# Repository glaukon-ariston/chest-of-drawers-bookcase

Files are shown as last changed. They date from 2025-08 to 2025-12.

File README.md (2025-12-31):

# Vibe Coding Furniture: Chest of Drawers Bookcase

This project contains the OpenSCAD code for a chest of drawers with an integrated bookcase.

## Prerequisites

- [Git](https://git-scm.com/downloads/win)
- [Node.js](https://nodejs.org/en/download/)
- [ezdxf](https://pypi.org/project/ezdxf/)
- [openpyxl](https://pypi.org/project/openpyxl/)
- [ODA File Converter](https://www.opendesign.com/guestfiles/oda_file_Converter)
- [LibreCAD](https://github.com/LibreCAD/LibreCAD/releases)
- [OpenSCAD](https://openscad.org/downloads.html#windows)
- [OpenSCAD (Nightly Build)](https://openscad.org/downloads.html#snapshots)
- [Gemini CLI](https://github.com/google-gemini/gemini-cli)
- [Visual Studio Code](https://code.visualstudio.com/)
- VS Code Extensions
    - Gemini Code Assist
    - Gemini CLI Companion
    - OpenSCAD

## Files

*   `model.scad`: The main OpenSCAD file containing the 3D model of the furniture.
*   `prompt/model.md`: The detailed instructions and dimensions used to generate the `model.scad` file.
*   `prompt/model-v2.md`: The updated instructions and dimensions for the v2 model.
*   `ps-modules/CommonFunctions.psm1`: A PowerShell module containing common functions used by the other scripts.
*   `artifacts/conversation.md`: A log of the conversation with Gemini CLI.
*   `workflow.ps1`: Orchestrates the entire workflow for generating various outputs from the OpenSCAD model.
*   `generate-csv.ps1`: Generates a CSV file with panel information.
*   `export-all.ps1`: Automates the export of all panels to various formats.
*   `export-panels.ps1`: Exports panels to a specific format (STL, DXF, SVG).
*   `run-split-layers.ps1`: Executes the `split-layers-dxf.ps1` script and logs the output.
*   `split_layers.py`: Python script to split DXF layers, add a title, annotations, a legend, a hole schedule and dimensions.
*   `convert-dxf-to-dwg.ps1`: Converts DXF files to DWG format using the ODA File Converter.
*   `convert-dxf-to-pdf.ps1`: Converts DXF files to PDF format using LibreCAD.
*   `create_order.py`: A Python script to generate an order document for the Iverpan cutting service.

## Model Description

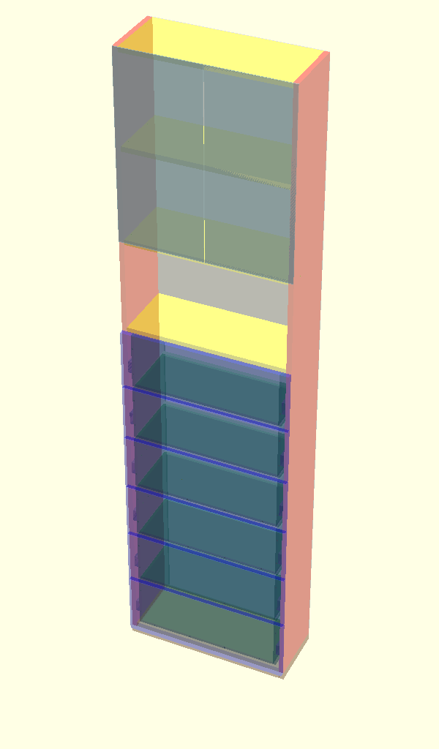
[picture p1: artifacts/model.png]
Model


The 3D model is a chest of drawers with an integrated bookcase. The design is parametric and all dimensions are derived from the main dimensions.

### Main Dimensions

*   **Corpus:**
    *   corpus_height = 2300
    *   corpus_width = 600
    *   corpus_depth = 230
*   **Melanine material thickness:**
    *   melanine_thickness_main = 18
    *   melanine_thickness_secondary = 10
*   **HDF Back Panel:**
    *   hdf_thickness = 3
*   **Pedestal:**
    *   pedestal_height = 30
*   **Shelves:**
    *   shelf_width = corpus_width - 2*melanine_thickness_main
    *   shelf_depth = corpus_depth
*   **Slides:**
    *   slide_width = 200
    *   slide_height = 45
    *   slide_depth = 13
*   **Drawers:**
    *   number_of_drawers = 6
    *   drawer_height = 200
    *   drawer_body_height = drawer_height - melanine_thickness_secondary
    *   drawer_depth = corpus_depth - 5
    *   drawer_width = shelf_width - 2*slide_depth
    *   drawer_body_width = drawer_width - 2*melanine_thickness_secondary
    *   drawer_bottom_offset = 10
    *   drawer_gap = 10
*   **Drawer Fronts:**
    *   front_gap = 3
    *   front_overhang = 3
    *   front_margin = 1.5
    *   front_width = corpus_width - 2 * front_margin
    *   front_height_base = drawer_height + drawer_gap - front_gap
    *   front_height_first = melanine_thickness_main + drawer_bottom_offset - front_gap + front_height_base
    *   front_height_standard = front_height_base
    *   front_height_top = front_height_standard + 3*front_overhang
*   **Bookcase Glass Doors:**
    *   bookcase_glass_door_width = (corpus_width - (1 + front_gap + 1))/2
    *   bookcase_glass_door_height = melanine_thickness_main + bookcase_shelf_gap + melanine_thickness_main + bookcase_shelf_gap + melanine_thickness_main/2
    *   bookcase_glass_door_tickness = 4
*   **Joinery:**
    *   confirmat_screw_length = 49
    *   confirmat_hole_diameter = 4
    *   confirmat_hole_edge_distance = 50
    *   dowel_diameter = 6
    *   dowel_length = 30
    *   dowel_hole_depth_in_front = 10
    *   dowel_hole_edge_distance = 50
    *   panel_length_for_four_dowels = 500
    *   slide_pilot_hole_depth = 2
    *   slide_pilot_hole_diameter = 2.5
    *   drawer_slide_pilot_hole_offsets = [37, 163]
    *   corpus_slide_pilot_hole_offsets = [6.5, 35, 51, 76, 99, 115]

### Structure

*   **Corpus:** The corpus is made of `melanine_thickness_main` thick melanine and consists of two sides, a top, a bottom and a middle plate. The corpus is divided into two compartments. The bottom compartment contains six drawers and the top compartment is a bookcase with two shelves.
*   **Drawers:** The drawers are made of `melanine_thickness_secondary` thick melanine and are mounted to the sides of the corpus with slides. Each drawer has a front panel made of `melanine_thickness_main` thick melanine. Dowel holes are included in the side and bottom panels for joining with the front panels. The drawer assembly has been fixed, and handle holes have been added to the drawer fronts.
*   **Shelves:** The bookcase has two shelves made of `melanine_thickness_main` thick melanine.
*   **HDF Back Panel:** A 3mm HDF back panel is attached to the back of the corpus.
*   **Pedestal:** A 30mm high pedestal is placed under the corpus.
*   **Glass Doors:** The bookcase section is enclosed by two glass doors.
*   **Joinery:** Confirmat screws (4.8mm x 49mm) are used to join the corpus panels and shelves. 4mm pilot holes for these screws are included in the model. The drawer components are also joined with these screws, with the number of screws depending on the panel length (2 for <50cm, 3 for >=50cm) and placed 5cm from the edge. Wooden dowels (phi 6 mm x 30 mm) are used to join the front panels to the drawer boxes. The front's blind hole is 1cm deep. There are two dowels per panel per side if the panel length is less than 50cm, and four dowels if longer, with even spacing. The hole locations are 5cm from the edge. Pilot holes for mounting the drawer slides are included in both the drawer sides and the corpus sides. These holes are 2mm deep and 2.5mm in diameter. In drawer sides, there are two holes per slide, located 37mm and 163mm from the front edge. ... In corpus sides, there are six holes per slide, located 6.5mm, 35mm, 51mm, 76, 99mm, and 115mm from the front edge.

### Cut List Generation

The model can generate a CSV cut list for all panels. This is controlled by the `generate_cut_list_csv` variable in `model.scad`. A PowerShell script, `generate-csv.ps1`, is provided to automate the process of generating the `artifacts/cut_list.csv` file.

### Order Generation

A Python script, `create_order.py`, is provided to automate the creation of an order document for a cutting service. The script uses the generated cut list CSV file and an Excel template to create a new Excel file with the order details.

### CNC Export

The project includes a workflow for exporting 2D panel drawings in DXF format, suitable for CNC cutting services. The `export-panels.ps1` script automates the export of all panels, and the `run-split-layers.ps1` script (which calls `split-layers-dxf.ps1` and `split_layers.py`) post-processes the DXF files to separate geometry into `CUT`, `DRILL`, and `DIMENSION` layers, and adds annotations for holes. The exported panels are positioned at the origin (0,0) to ensure consistency. The annotations include a detailed "Hole Schedule" table with the hole name, diameter, depth, and its X, Y, and Z coordinates.

#### DXF Post-processing

The `split_layers.py` script performs several post-processing steps on the DXF files generated by OpenSCAD:
*   It separates entities into `CUT`, `DRILL`, `DIMENSION`, and `ANNOTATION` layers.
*   It adds detailed hole annotations and a hole schedule table.
*   It detects and converts circle-like polylines into true `CIRCLE` entities to address a common OpenSCAD export issue where circles are exported as segmented polylines.
*   It classifies small `ARC` entities as drill holes.

#### DXF to DWG Conversion

The `split-layers-dxf.ps1` script also handles the conversion of the layered DXF files to DWG format using the ODA File Converter in batch mode.

#### DXF to PDF Conversion

A PowerShell script, `convert-dxf-to-pdf.ps1`, is provided to convert the layered DXF files to PDF format using LibreCAD.

#### Printing Drilling Templates

The generated PDF templates can be printed to scale and used as physical templates for drilling. Here's how to do it using LibreCAD's built-in print tiling feature. For more details, see the [LibreCAD documentation](https://docs.librecad.org/en/2.2.0_a/guides/completion.html#print-preview-window).

1.  **Set up your paper size:**
    *   Go to `File` → `Print Preview`.
    *   Click the `Options` toolbar icon (looks like a gear ⚙️).
    *   Under `Paper`, choose:
        *   `A4`
        *   `Orientation`: `Portrait` or `Landscape` depending on your drawing.
        *   Set `Margins` to small values (e.g., 3-5 mm).

2.  **Set scale:**
    *   In `Print Preview`, check `Fixed` and set `Scale = 1.0` (for 1:1).

3.  **Move the drawing into position:**
    *   Use the `Move/Drag` tool in `Print Preview` to shift the viewport.
    *   Position the first A4 sheet over the area you want to print.

4.  **Print to PDF:**
    *   Click `Print` → choose 'Microsoft Print to PDF' (or another PDF printer).
    *   Name it e.g. `part_01.pdf`.

5.  **Repeat for other tiles:**
    *   Shift the viewport by exactly one A4 page width or height each time.
    *   Print again (e.g. `part_02.pdf`, `part_03.pdf`, etc.).
    *   You can overlap slightly if needed to ensure continuity.

## Changelog

### v27

*   **Bug Fixes:**
    *   Fixed a bug in `drawer_front_drill` and `drawer_front_hole_metadata` where the X-coordinates for drawer side dowel holes were aligned with the inner faces rather than the center of the panel thickness. The holes are now correctly centered.
*   **Test Scripts:**
    *   Added `test/test-drawer-front-alignment.ps1` to verify the X-axis alignment of drawer front holes with the drawer box assembly.

### v26

*   **Bug Fixes:**
    *   Fixed the vertical offset of dowel holes in drawer front panels (`DrawerFrontBottom`, `DrawerFrontStandard`, `DrawerFrontTop`) and related templates (`DrawerFrontOutsideTemplate`). The holes are now correctly shifted by the `front_overhang` (3mm) plus any drawer offset, ensuring they align perfectly with the corresponding holes in the drawer side panels.
*   **Order Generation:**
    *   Updated `create_order.py` to use `HDF-3-Bijela` (White HDF) instead of `HDF-3-Hrast` for the Iverpan cutting service.
*   **Test Scripts:**
    *   Added `test/test-front-overhang.ps1` to verify the drawer front hole offsets.

### v25

*   **Template Panels:**
    *   Increased the height of `CorpusShelfTemplate` by `melanine_thickness_main` to facilitate sequential placement for drilling shelf holes in the corpus side.

### v24

*   **Template Panels:**
    *   Added `DrawerFrontOutsideTemplate` panel.
    *   Renamed `DrawerFrontTemplate` to `DrawerFrontInsideTemplate`.

### v23

*   **Template Panels:**
    *   Added handle holes to the `DrawerFrontInsideTemplate` panel.
*   **Test Scripts:**
    *   Added `test/test-drawer-front-template.ps1` to test the export of the `DrawerFrontInsideTemplate` panel.

### v22

*   **Bug Fixes:**
    *   Fixed a bug where the bottom hole for connecting the drawer side to the back panel was incorrectly positioned at 50mm from the edge, causing interference with the slide mechanism. The hole is now correctly positioned at 35mm from the edge.
*   **Model Parameterization:**
    *   Updated `drawer_slide_pilot_hole_offsets` from `[37, 165]` to `[37, 163]`.

### v21

*   **Model Parameterization:**
    *   Updated `drawer_slide_pilot_hole_offsets` from `[35, 163]` to `[37, 165]`.
*   **OpenSCAD Output:**
    *   Added `model_info` object to console output for structured parameter access.
    *   Prefixed cut list entries with `CSV:` for easier parsing.
    *   Prefixed panel names with `panel=` and model identifier with `model_identifier=` in console output.
*   **PowerShell Scripts:**
    *   All PowerShell scripts now use `Import-Module -Force` to ensure the latest module changes are always loaded.
*   **DXF Export:**
    *   Removed 3D object generation from `pedestal_side_template_hole_metadata` to fix DXF export issues.
    *   Updated `split_layers.py` to expect `nx,ny,nz` in hole metadata CSV.
*   **PowerShell Modules:**
    *   Improved parsing logic in `Get-ModelIdentifier` and `Get-PanelNames` in `CommonFunctions.psm1` for robustness against OpenSCAD output variations.
*   **Test Scripts:**
    *   Added `test/get-export-folder.ps1`, `test/export-panel.ps1`, and `test/get-panel-names.ps1`.
    *   Normalized export folder path in `test/get-export-folder.ps1`.

### v20

*   **DXF Export:**
    *   Added unit vector components (nx, ny, nz) to the hole metadata CSV export, indicating the normal vector of the panel surface at the hole location.

### v19

*   **DXF Export:**
    *   Moved the legend below the "Hole Schedule" table and matched the font size for better readability.
    *   The legend title font size is now the same as the "Hole Schedule" title.

### v18

*   **DXF Export:**
    *   Added a new `DRILL_MARKS` layer to display black crosshair markers for planar drill holes, distinguishing them from side-drilled holes.
    *   Added a `--template` flag to `split_layers.py` to generate a clean DXF output without dimension lines, title, legend, or hole schedule, suitable for use as a drilling template.

### v17

*   **Model Parameterization:**
    *   Changed `melanine_thickness_main` from 19 to 18.
    *   Changed `melanine_thickness_secondary` from 12 to 10.
*   **Order Generation:**
    *   Updated `create_order.py` to correctly handle banding for the 'Sizekupres' service.
    *   Updated material codes for the 'Elgrad' service.
*   **Template Panels:**
    *   Changed the material for template panels from 12mm to 18mm melanine.

### v16

*   **Order Generation:**
    *   Added support for the 'Sizekupres' cutting service in `create_order.py`.
*   **Workflow:**
    *   The `workflow.ps1` script now automates the generation of order files for all supported cutting services.
*   **DXF Processing:**
    *   Fixed a bug in `split_layers.py` where `LINE` entities for holes were not being correctly identified due to a strict `isclose()` tolerance. A tolerance is now used to correctly match line segments.

### v15

*   **Template Panels:**
    *   Added `PedestalSideTemplate`, `DrawerBackTemplate`, and `DrawerSideTemplate`.
    *   Fixed missing slide mount pilot holes in `DrawerSideTemplate`.
*   **DXF Export:**
    *   Increased the circle segment count (`$FN`) to 100 in `model.scad` to improve circle quality in DXF exports.
    *   In `split_layers.py`, implemented a feature to detect and convert circle-like polylines into true `CIRCLE` entities, addressing an OpenSCAD export issue.
    *   Small `ARC` entities are now correctly classified to the `DRILL` layer.
    *   Changed the `DIMENSION` layer color to grey and the `ANNOTATION` layer color to black for better visibility.
    *   The dimension text is now placed above the dimension line, and the line does not cross over the text.
*   **Debugging:**
    *   Added a statistics generation feature to `split_layers.py` to provide an overview of DXF entity types and sizes upon processing.

### v14

*   **Order Generation:**
    *   Refactored `create_order.py` to support the 'Furnir' cutting service.
    *   The material definitions are now in a nested dictionary `MATERIAL` to support multiple services.
*   **Configuration:**
    *   Added `.vscode` to the `.gitignore` file.

### v13

*   **Model Parameterization:**
    *   Changed `melanine_thickness_main` from 19 to 18.
*   **DXF Export:**
    *   Corrected the 2D projection for `DrawerSideLeft`, `DrawerSideRight`, and `DrawerBack` panels to ensure correct orientation and placement in the first quadrant.
    *   Updated the hole metadata functions (`get_drawer_side_hole_2d_coords`, `get_drawer_back_hole_2d_coords`) to match the new projections.
*   **Bug Fixes:**
    *   Fixed an incorrect hole position in the `drawer_side_drill` and `drawer_side_hole_metadata` modules for the rear confirmat screw connecting the drawer side to the bottom panel.
*   **Order Generation:**
    *   Refactored `create_order.py` to support multiple materials for the Elgrad cutting service.
*   **Documentation:**
    *   Updated `export-panels.ps1` with more detailed comments.
*   **DXF Processing:**
    *   Removed debug print statements from `split_layers.py`.

### v12

*   **Order Generation:**
    *   The `create_order.py` script has been refactored to support multiple cutting services (Iverpan and Elgrad).
    *   The script now accepts `--service` and `--template` arguments for greater flexibility.
    *   The output directory for orders is now `order/export/{model_id}`.
*   **Workflow:**
    *   The `workflow.ps1` script has been updated to automate the entire process, including the generation of order files for both Iverpan and Elgrad.
*   **Configuration:**
    *   The `.gitignore` file has been updated to exclude the new `order/export` directory from version control.

### v11

*   **DXF Export:**
    *   A title with the panel name is now added to the top of each DXF drawing.
    *   The hole name is now included in the hole annotations for easier identification.

### v10

*   **Documentation:**
    *   The `README.md` and `GEMINI.md` files have been updated to include a comprehensive list of all source files.
    *   An image of the model is now included in `README.md`.
*   **Workflow:**
    *   The `workflow.ps1` script now automatically generates the `artifacts/model.png` image used in the documentation.
*   **Model:**
    *   The `export_panel_name` variable in `model.scad` is now empty by default to prevent accidental exports.

### v9

*   **Model Parameterization:**
    *   The `corpus_width` has been changed from 800mm to 600mm, making the model more compact.
*   **Workflow Automation:**
    *   The `workflow.ps1` script has been enhanced to automate the entire export and conversion process.
    *   The export directory is now dynamically created based on the model's dimensions.
*   **Script Refactoring:**
    *   All PowerShell scripts have been refactored to use a new `CommonFunctions.psm1` module.
*   **Bug Fixes:**
    *   Fixed a bug in the bounding box calculation in `split_layers.py` for `ARC` entities.

### v8

*   **Model Parameterization:**
    *   The `corpus_width` has been changed from 800mm to 600mm, making the model more compact.
*   **Workflow Automation:**
    *   Added a new PowerShell script, `workflow.ps1`, to automate the entire export and conversion process, including CSV cut list generation, DXF/STL/SVG export, DXF layering, and DXF to DWG/PDF conversion.
    *   The export directory is now dynamically created based on the model's dimensions, allowing for multiple model configurations to coexist.

### v7

*   **DXF to PDF Conversion:**
    *   Added a new PowerShell script, `convert-dxf-to-pdf.ps1`, to automate the conversion of DXF files to PDF format using LibreCAD.
    *   The script is hardened against LibreCAD's unreliable exit code by verifying the existence of the output PDF file instead of checking the exit code.

### v6

*   **DXF to DWG Conversion:**
    *   The `split-layers-dxf.ps1` script has been enhanced to automatically convert layered DXF files to DWG format using the ODA File Converter in batch mode. This ensures silent and efficient conversion.

### v5

*   **Enhanced Hole Visualization in DXF Export:**
    *   The `split_layers.py` script now includes the Z-coordinate in the text annotations for side-drilled holes (holes where the Z-coordinate is non-zero), providing clearer manufacturing information.
    *   A small cross symbol is now added at the (X,Y) location of side-drilled holes on the `DRILL` layer in 2D panel projections, serving as a visual indicator to distinguish them from through-holes or face-drilled holes.

### v4

*   Added a `DIMENSION` layer to the DXF export for panel and hole dimensions.
*   The dimensioning logic is optimized to avoid overlapping lines and redundant information.
*   Dimension text is now placed above the dimension line with a background fill for better readability.

### v3

*   Corrected the 2D hole coordinate calculation for DXF export.
*   All exported 2D panels are now positioned at the origin (0,0).
*   Added a detailed "Hole Schedule" table to the DXF annotations.
*   The Z-coordinate in the hole metadata is now correctly represented.

### v2

*   The number of drawers is now configurable.
*   The drawer assembly has been fixed. The back panel of the drawer is now correctly positioned.
*   The model has been made more parametric.
*   Added 4mm pilot holes for confirmat screws to join the drawer components.
*   The file `prompt/model-v2.md` has been added to reflect the changes in the model.
*   Added handle holes to drawer fronts.
*   Added transparency to the model for better visualization.
*   Added pilot holes for drawer slides in the corpus sides.
*   Added a configurable exploded view to visualize the assembly.
*   Added an HDF back panel to the corpus.
*   Added a pedestal to the bottom of the corpus.
*   Added glass doors to the bookcase section.
*   Added a feature to generate a CSV cut list.
*   Replaced the batch script for CSV generation with a more robust PowerShell script.
*   Standardized all panel names to single-word strings (e.g., `CorpusSideLeft`) for consistency and easier use in scripts.
*   Updated the cut list to include CNC comments.
*   Added a CNC export workflow using PowerShell and Python scripts to generate layered DXF files.
*   Fixed SVG export for panels with non-through holes by ensuring the holed face is on the `z=0` plane during projection.
*   Added a PowerShell script `split-layers-dxf.ps1` to automate the layering of DXF files.
*   Added a Python script `analyze_dxf.py` to analyze the layers in the generated DXF files.
*   Removed in-model text annotations for hole dimensions and locations to speed up DXF export.
*   The `split_layers.py` script now adds annotations to the DXF files based on the hole metadata exported from OpenSCAD.
*   Added a hole metadata export feature to generate CSV files with hole locations, which are then used to create annotations in the DXF files.

## Usage

To view the 3D model, open the `model.scad` file in [OpenSCAD](https://openscad.org/).

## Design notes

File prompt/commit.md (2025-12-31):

feat(model): Center drawer front dowel holes

This commit fixes a bug in the model where the dowel holes on the drawer fronts were not correctly aligned with the center of the drawer side panels. They were previously aligned to the inner face of the side panels.

Key changes:
- **`model.scad`**:
    - In `drawer_front_drill` and `drawer_front_hole_metadata`, the X-coordinate calculation for the side panel dowel holes has been adjusted. It now correctly offsets the holes from the inner face position by half of `melanine_thickness_secondary` to perfectly center them.
- **`test/test-drawer-front-alignment.ps1`**:
    - A new test script has been added to programmatically verify the X-axis alignment of the drawer front holes. This test exports the `DrawerFrontStandard` panel, parses the hole metadata, and asserts that the X-coordinates match the calculated center positions.
- **Documentation**:
    - The `README.md`, `GEMINI.md`, and `prompt/model-v2.md` files have been updated with a new changelog entry (v27) to reflect this fix and the addition of the new test script.

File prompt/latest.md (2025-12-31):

The drawer_front_drill() has a bug. The x coordinate needs to be offset inward by melanine_thickness_secondary/2 in order for the holes to align with the drawer box holes. For example, the left side holes' x coordinate needs to be (front_width - drawer_body_width)/2+melanine_thickness_secondary/2.

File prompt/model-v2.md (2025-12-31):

# Chest of Drawers Bookcase: Model Description

This document provides a detailed description of the OpenSCAD model for the chest of drawers with an integrated bookcase. It outlines the design decisions, parametric setup, and modular structure of the `model.scad` file.

## 1. Overview

The model is a piece of furniture combining a six-drawer chest of drawers with a bookcase on top. The design is fully parametric, meaning the entire model can be resized by changing a few key variables. The model is built in a modular way in OpenSCAD, allowing for easy customization and debugging. The model also includes transparency for better visualization.

## 2. Parametric Design

The model is driven by a set of global parameters defined at the beginning of the `model.scad` file. This allows for easy modification of the overall dimensions and material thicknesses. The variable names are chosen to be descriptive for better readability.

### Main Dimensions

*   **Corpus:**
    *   corpus_height = 2300
    *   corpus_width = 600
    *   corpus_depth = 230
*   **Melanine material thickness:**
    *   melanine_thickness_main = 18
    *   melanine_thickness_secondary = 10
*   **HDF Back Panel:**
    *   hdf_thickness = 3
*   **Pedestal:**
    *   pedestal_height = 30
*   **Shelves:**
    *   shelf_width = corpus_width - 2*melanine_thickness_main
    *   shelf_depth = corpus_depth
*   **Slides:**
    *   slide_width = 200
    *   slide_height = 45
    *   slide_depth = 13
*   **Drawers:**
    *   number_of_drawers = 6
    *   drawer_height = 200
    *   drawer_body_height = drawer_height - melanine_thickness_secondary
    *   drawer_depth = corpus_depth - 5
    *   drawer_width = shelf_width - 2*slide_depth
    *   drawer_body_width = drawer_width - 2*melanine_thickness_secondary
    *   drawer_bottom_offset = 10
    *   drawer_gap = 10
*   **Drawer Fronts:**
    *   front_gap = 3
    *   front_overhang = 3
    *   front_margin = 1.5
    *   front_width = corpus_width - 2 * front_margin
    *   front_height_base = drawer_height + drawer_gap - front_gap
    *   front_height_first = melanine_thickness_main + drawer_bottom_offset - front_gap + front_height_base
    *   front_height_standard = front_height_base
    *   front_height_top = front_height_standard + 3*front_overhang
*   **Bookcase Glass Doors:**
    *   bookcase_glass_door_width = (corpus_width - (1 + front_gap + 1))/2
    *   bookcase_glass_door_height = melanine_thickness_main + bookcase_shelf_gap + melanine_thickness_main + bookcase_shelf_gap + melanine_thickness_main/2
    *   bookcase_glass_door_tickness = 4
*   **Joinery:**
    *   confirmat_screw_length = 49
    *   confirmat_hole_diameter = 4
    *   confirmat_hole_edge_distance = 50
    *   dowel_diameter = 6
    *   dowel_length = 30
    *   dowel_hole_depth_in_front = 10
    *   dowel_hole_edge_distance = 50
    *   panel_length_for_four_dowels = 500
    *   slide_pilot_hole_depth = 2
    *   slide_pilot_hole_diameter = 2.5
    *   drawer_slide_pilot_hole_offsets = [37, 163]
    *   corpus_slide_pilot_hole_offsets = [6.5, 35, 51, 76, 99, 115]

All other dimensions for components like shelves, drawer parts, and front panels are derived from these base parameters.

## 3. Component Breakdown

The model is broken down into several distinct components, each with its own OpenSCAD module for easy identification and manipulation.

### 3.1. Corpus

-   The main body of the furniture.
-   Consists of two side panels, a top plate, a bottom plate, and a middle plate that separates the drawers from the bookcase section.
-   Constructed from `melanine_thickness_main` material.
-   The corpus is divided into two compartments. The bottom compartment contains six drawers and the top compartment is a bookcase with two shelves.

### 3.2. Drawers

-   The drawers are made of `melanine_thickness_secondary` thick melanine and are mounted to the sides of the corpus with slides.
-   Each drawer has a front panel made of `melanine_thickness_main` thick melanine.
-   Dowel holes are included in the side and bottom panels for joining with the front panels.
-   The drawer assembly has been fixed, and the back panel of the drawer is now correctly positioned.

### 3.3. Drawer Fronts

-   The drawer fronts are separate from the drawer boxes and are made from `melanine_thickness_main` material.
-   Dowel holes are included for joining with the drawer boxes.
-   The design includes a consistent vertical `front_gap` between each front.
-   Handle holes have been added to drawer fronts.

### 3.4. Shelves

-   The bookcase has two shelves made of `melanine_thickness_main` thick melanine.

### 3.5. Slides

-   Represents the drawer slides that mount to the corpus sides.
-   These are modeled as simple blocks to correctly space the drawer boxes within the corpus.

### 3.6. HDF Back Panel

-   A 3mm HDF back panel is attached to the back of the corpus.

### 3.7. Pedestal

-   A 30mm high pedestal is placed under the corpus.

### 3.8. Glass Doors

-   The bookcase section is enclosed by two glass doors.

### 3.9. Template Panels

-   The model includes three template panels for drilling holes:
    -   `CorpusSideSlideTemplate`: A template for drilling slide mounting pilot holes on the corpus sides.
    -   `DrawerFrontTemplate`: A template for drilling wooden dowel mounting holes for the front panel.
    -   `CorpusShelfTemplate`: A template for drilling shelf mounting holes.
    -   `PedestalSideTemplate`: A template for drilling holes in the pedestal sides.
    -   `DrawerBackTemplate`: A template for drilling holes to the drawer back panel.
    -   `DrawerSideTemplate`: A template for drilling holes for the slide mount to the drawer side panel.

## 4. Joinery

-   **Corpus and Shelves:** Confirmat screws (4.8mm x 49mm) are used to join the corpus panels and shelves. 4mm pilot holes for these screws are included in the model.
-   **Drawers:** The drawer components are also joined with these screws, with the number of screws depending on the panel length (2 for <50cm, 3 for >=50cm) and placed 5cm from the edge. 4mm pilot holes for confirmat screws to join the drawer components have been added.
-   **Wooden Dowels:** Wooden dowels (phi 6 mm x 30 mm) are used to join the front panels to the drawer boxes. The front's blind hole is 1cm deep. There are two dowels per panel per side if the panel length is less than 50cm, and four dowels if longer, with even spacing. The hole locations are 5cm from the edge.
-   **Slide Pilot Holes:** Pilot holes for mounting the drawer slides are included in both the drawer sides and the corpus sides. These holes are 2mm deep and 2.5mm in diameter.
    -   **In Drawer Sides:** Two holes per slide, located 37mm and 163mm from the front edge.
    -   **In Corpus Sides:** Six holes per slide, located 6.5mm, 35mm, 51mm, 76, 99mm, and 115mm from the front edge.

## 5. Code Structure & Modularity

The `model.scad` file is structured for clarity and ease of use.

### 5.1. Component Modules

Each individual part (e.g., `corpus_side`, `drawer_bottom`) is defined in its own module. These are then assembled into more complex components (e.g., a full `drawer` or the `corpus`).

### 5.2. Drawing Modules & Debugging Flags

To aid in debugging and visualization, the final assembly is handled by a set of `draw_*` modules:

-   `draw_corpus()`
-   `draw_drawers()`
-   `draw_slides()`
-   `draw_fronts()`
-   `draw_shelves()`
-   `draw_glass_doors()`
-   `draw_hdf_back_panel()`
-   `draw_pedestal()`

The visibility of each of these component groups is controlled by a set of boolean flags at the top of the file (e.g., `show_corpus`). This allows a user to selectively render parts of the model to inspect specific areas without visual clutter.

## 6. Debugging and Verification

To assist with verifying the parametric design, key calculated dimensions are printed to the OpenSCAD console using the `echo()` function. This includes values like the position of the middle plate, the spacing of the shelves, and the dimensions of the drawers and doors. This allows for quick verification of the model's dimensions without needing to manually measure the 3D view.

Additionally, a comprehensive `model_info` object is now echoed to the console, containing all critical model parameters and derived dimensions in a structured format. This provides a single, easily parsable source of truth for the model's current configuration, which can be used by external scripts for validation or further processing.

## 7. Exploded View

The model includes an exploded view feature to help visualize how the components are assembled. This feature can be enabled by setting the `exploded_view` variable to `true`. The `explosion_factor` variable controls the distance between the exploded parts. The exploded view is now more sophisticated, with individual explosion for different component groups.

## 8. Cut List Generation

The `model.scad` file includes a feature to generate a CSV (Comma-Separated Values) cut list for all the panels required to build the furniture. This cut list includes panel dimensions, materials, quantities, edge banding requirements, and CNC comments. Each line of the cut list is now prefixed with "CSV: " in the OpenSCAD console output to facilitate easier parsing by external scripts.

To generate the cut list, set the `generate_cut_list_csv` variable to `true` at the top of the `model.scad` file. When the model is rendered, the cut list data will be printed to the OpenSCAD console. This data can then be saved to a CSV file.

For a more automated process, the `generate-csv.ps1` PowerShell script is provided. This script runs OpenSCAD, captures the console output, and saves the cleaned CSV data to `artifacts/cut_list.csv`.

## 9. CNC Export Workflow

The project includes a workflow for exporting the 2D panel drawings in DXF format, suitable for CNC cutting services.

To improve reliability and ensure that the latest changes to shared PowerShell modules are always picked up, all PowerShell scripts involved in the CNC export workflow now use `Import-Module -Force`. This prevents issues caused by module caching in active PowerShell sessions.

The workflow consists of two main steps:
1.  **Exporting Panels from OpenSCAD:** The `export-panels.ps1` PowerShell script automates the export of all panels to the `artifacts/export` directory. The script gets the list of panels from the `model.scad` file and then calls OpenSCAD for each panel to generate a DXF file. All exported panels are positioned at the origin (0,0) to ensure consistency.
2.  **Layering DXF Files:** The `run-split-layers.ps1` script executes the `split-layers-dxf.ps1` script, which processes the exported DXF files using the `split_layers.py` Python script to separate the geometry into `CUT`, `DRILL`, and `DIMENSION` layers. This is necessary because OpenSCAD exports all geometry to a single layer. The script uses the `ezdxf` library to perform this operation.

This workflow ensures that the final DXF files are ready for use with CAM software, with clean separation between cutting paths and drill holes.

### 9.3. DXF to DWG Conversion

The `split-layers-dxf.ps1` script has been enhanced to automatically convert the layered DXF files to DWG format using the ODA File Converter. This conversion is performed in batch mode, ensuring a silent and efficient process. The converted DWG files are saved in the `artifacts/export/dwg` directory.

### 9.4. DXF to PDF Conversion

A PowerShell script, `convert-dxf-to-pdf.ps1`, is provided to convert the layered DXF files to PDF format using LibreCAD. Due to a known issue where LibreCAD's `dxf2pdf` tool returns an incorrect exit code on success, the script verifies the conversion by checking for the creation of the output PDF file rather than relying on the exit code.

### 9.5. Template Generation

The `split_layers.py` script includes a `--template` flag that generates a clean DXF file without dimension lines, title, legend, or hole schedule. This clean DXF file is then used by the `convert-dxf-to-pdf.ps1` script to create a corresponding PDF file. This provides a clean, to-scale drawing that can be printed and used as a physical template for drilling and cutting.

## 10. DXF Analysis

To verify that the DXF files have been correctly layered, the `analyze_dxf.py` script is provided. This script takes a directory as input and analyzes all the DXF files in that directory, printing a summary of the layers and the number of entities on each layer.

## 11. Hole Metadata Export

To facilitate the creation of manufacturing documentation, the model can now export detailed metadata for all holes on a given panel. This metadata includes the hole's name, its 2D projected coordinates (x, y), its Z coordinate (relative to the panel's thickness), its diameter, its depth, and a unit vector (nx, ny, nz) representing the normal of the panel surface at the hole location.

This is achieved through a series of new functions and modules:

- **`get_*_hole_2d_coords()` functions:** These functions are responsible for calculating the 2D projected coordinates of a hole based on the panel's export transformation.
- **`*_hole_metadata()` modules:** Each panel type with holes has a corresponding module that uses the coordinate transformation functions to `echo` the hole metadata to the OpenSCAD console during export. The Z coordinate is now correctly represented, with a value of `0` for holes drilled perpendicularly into the panel face and a value of half the panel's thickness for holes drilled into the edge.
- **`echo_hole_metadata()` module:** This top-level module is called during the export process and, based on the `export_panel_name` variable, it calls the appropriate `*_hole_metadata()` module to generate the metadata for the specified panel.

The `export-panels.ps1` script has been updated to capture this metadata from the console output and save it to a CSV file named after the panel (e.g., `CorpusSideLeft.csv`) in the `artifacts/export/dxf-raw` directory.

The `split_layers.py` script has also been updated to read these CSV files and add text annotations to the DXF files on a new `ANNOTATION` layer. This includes a detailed "Hole Schedule" table with the hole name, diameter, depth, and its X, Y, and Z coordinates. For side-drilled holes (where Z is non-zero), the Z-coordinate is included in the annotation (e.g., `d10 h20 z5`), and a blue cross symbol is added on the `DRILL` layer at the hole's (X,Y) location as a visual indicator. This provides a fully automated workflow for generating richly annotated DXF files ready for manufacturing.

## 13. Workflow Automation

The `workflow.ps1` script has been added to automate the entire export and conversion process. This script performs the following steps:
1.  Generates the CSV cut list.
2.  Exports all panels to DXF, STL, and SVG formats.
3.  Splits the DXF files into layers.
4.  Converts the layered DXF files to DWG.
5.  Converts the layered DXF files to PDF.
6.  Generates order files for Iverpan and Elgrad.

## 14. Known Issues

*   The bounding box calculation for text entities in `split_layers.py` is not accurate. It only considers the insertion point, which may result in incorrect placement of dimensions and legends in some cases.

## 16. Order Generation

A Python script, `create_order.py`, is provided to automate the creation of an order document for a cutting service. The script uses the generated cut list CSV file and an Excel template to create a new Excel file with the order details.

### Usage

```bash
python create_order.py --model-id <model_identifier> --service <service_name> --template <template_file>
```

- `--model-id`: The identifier of the model (e.g., `H2300xW600xD230_Mm19_Ms12`).
- `--service`: The cutting service provider (e.g., `iverpan`, `elgrad`, `furnir`, `sizekupres`).
- `--template`: The path to the Excel template file.

## 16. Changelog

### v27

*   **Bug Fixes:**
    *   Fixed a bug in `drawer_front_drill` and `drawer_front_hole_metadata` where the X-coordinates for drawer side dowel holes were aligned with the inner faces rather than the center of the panel thickness. The holes are now correctly centered.
*   **Test Scripts:**
    *   Added `test/test-drawer-front-alignment.ps1` to verify the X-axis alignment of drawer front holes with the drawer box assembly.

### v26

*   **Bug Fixes:**
    *   Fixed the vertical offset of dowel holes in drawer front panels (`DrawerFrontBottom`, `DrawerFrontStandard`, `DrawerFrontTop`) and related templates (`DrawerFrontOutsideTemplate`). The holes are now correctly shifted by the `front_overhang` (3mm) plus any drawer offset, ensuring they align perfectly with the corresponding holes in the drawer side panels.
*   **Order Generation:**
    *   Updated `create_order.py` to use `HDF-3-Bijela` (White HDF) instead of `HDF-3-Hrast` for the Iverpan cutting service.
*   **Documentation:**
    *   Added a changelog entry for v26.

### v25

*   **Template Panels:**
    *   Increased the height of `CorpusShelfTemplate` by `melanine_thickness_main` to facilitate sequential placement for drilling shelf holes in the corpus side.

### v24

*   **Template Panels:**
    *   Added `DrawerFrontOutsideTemplate` panel.
    *   Renamed `DrawerFrontTemplate` to `DrawerFrontInsideTemplate`.

### v23

*   **Template Panels:**
    *   Added handle holes to the `DrawerFrontInsideTemplate` panel.

### v22

*   **Bug Fixes:**
    *   Fixed a bug where the bottom hole for connecting the drawer side to the back panel was incorrectly positioned at 50mm from the edge, causing interference with the slide mechanism. The hole is now correctly positioned at 35mm from the edge.
*   **Model Parameterization:**
    *   Updated `drawer_slide_pilot_hole_offsets` from `[37, 165]` to `[37, 163]`.

### v21

*   **Model Parameterization:**
    *   Updated `drawer_slide_pilot_hole_offsets` from `[35, 163]` to `[37, 165]`.
*   **OpenSCAD Output:**
    *   Added `model_info` object to console output for structured parameter access.
    *   Prefixed cut list entries with `CSV:` for easier parsing.
    *   Prefixed panel names with `panel=` and model identifier with `model_identifier=` in console output.
*   **PowerShell Scripts:**
    *   All PowerShell scripts now use `Import-Module -Force` to ensure the latest module changes are always loaded.
*   **DXF Export:**
    *   Removed 3D object generation from `pedestal_side_template_hole_metadata` to fix DXF export issues.
    *   Updated `split_layers.py` to expect `nx,ny,nz` in hole metadata CSV.
*   **PowerShell Modules:**
    *   Improved parsing logic in `Get-ModelIdentifier` and `Get-PanelNames` in `CommonFunctions.psm1` for robustness against OpenSCAD output variations.
*   **Test Scripts:**
    *   Added `test/get-export-folder.ps1`, `test/export-panel.ps1`, and `test/get-panel-names.ps1`.
    *   Normalized export folder path in `test/get-export-folder.ps1`.

### v20

*   **DXF Export:**
    *   Added unit vector components (nx, ny, nz) to the hole metadata CSV export, indicating the normal vector of the panel surface at the hole location.
*   **Documentation:**
    *   Added instructions for printing drilling template PDFs to `README.md`.

### v19

*   **DXF Export:**
    *   Moved the legend below the "Hole Schedule" table and matched the font size for better readability.
    *   The legend title font size is now the same as the "Hole Schedule" title.

### v18

*   **DXF Export:**
    *   Added a new `DRILL_MARKS` layer to display black crosshair markers for planar drill holes, distinguishing them from side-drilled holes.
    *   Added a `--template` flag to `split_layers.py` to generate a clean DXF output without dimension lines, title, legend, or hole schedule, suitable for use as a drilling template.

### v17

*   **Model Parameterization:**
    *   Changed `melanine_thickness_main` from 19 to 18.
    *   Changed `melanine_thickness_secondary` from 12 to 10.
*   **Order Generation:**
    *   Updated `create_order.py` to correctly handle banding for the 'Sizekupres' service.
    *   Updated material codes for the 'Elgrad' service.
*   **Template Panels:**
    *   Changed the material for template panels from 12mm to 18mm melanine.

### v16

*   **Order Generation:**
    *   Added support for the 'Sizekupres' cutting service in `create_order.py`.
*   **Workflow:**
    *   The `workflow.ps1` script now automates the generation of order files for all supported cutting services.
*   **DXF Processing:**
    *   Fixed a bug in `split_layers.py` where `LINE` entities for holes were not being correctly identified due to a strict `isclose()` tolerance. A tolerance is now used to correctly match line segments.

### v15

*   **Template Panels:**
    *   Added `PedestalSideTemplate`, `DrawerBackTemplate`, and `DrawerSideTemplate`.
    *   Fixed missing slide mount pilot holes in `DrawerSideTemplate`.
*   **DXF Export:**
    *   Increased the circle segment count (`$FN`) to 100 in `model.scad` to improve circle quality in DXF exports.
    *   In `split_layers.py`, implemented a feature to detect and convert circle-like polylines into true `CIRCLE` entities, addressing an OpenSCAD export issue.
    *   Small `ARC` entities are now correctly classified to the `DRILL` layer.
    *   Changed the `DIMENSION` layer color to grey and the `ANNOTATION` layer color to black for better visibility.
    *   The dimension text is now placed above the dimension line, and the line does not cross over the text.
*   **Debugging:**
    *   Added a statistics generation feature to `split_layers.py` to provide an overview of DXF entity types and sizes upon processing.

### v14

*   **Order Generation:**
    *   Refactored `create_order.py` to support the 'Furnir' cutting service.
    *   The material definitions are now in a nested dictionary `MATERIAL` to support multiple services.
*   **Configuration:**
    *   Added `.vscode` to the `.gitignore` file.

### v13

*   **Model Parameterization:**
    *   Changed `melanine_thickness_main` from 19 to 18.
*   **DXF Export:**
    *   Corrected the 2D projection for `DrawerSideLeft`, `DrawerSideRight`, and `DrawerBack` panels to ensure correct orientation and placement in the first quadrant.
    *   Updated the hole metadata functions (`get_drawer_side_hole_2d_coords`, `get_drawer_back_hole_2d_coords`) to match the new projections.
*   **Bug Fixes:**
    *   Fixed an incorrect hole position in the `drawer_side_drill` and `drawer_side_hole_metadata` modules for the rear confirmat screw connecting the drawer side to the bottom panel.
*   **Order Generation:**
    *   Refactored `create_order.py` to support multiple materials for the Elgrad cutting service.
*   **Documentation:**
    *   Updated `export-panels.ps1` with more detailed comments.
*   **DXF Processing:**
    *   Removed debug print statements from `split_layers.py`.

### v12

*   **Order Generation:**
    *   The `create_order.py` script has been refactored to support multiple cutting services (Iverpan and Elgrad).
    *   The script now accepts `--service` and `--template` arguments for greater flexibility.
    *   The output directory for orders is now `order/export/{model_id}`.
*   **Workflow:**
    *   The `workflow.ps1` script has been updated to automate the entire process, including the generation of order files for both Iverpan and Elgrad.
*   **Configuration:**
    *   The `.gitignore` file has been updated to exclude the new `order/export` directory from version control.

### v11

*   **DXF Export:**
    *   A title with the panel name is now added to the top of each DXF drawing.
    *   The hole name is now included in the hole annotations for easier identification.

### v10

*   **Documentation:**
    *   The `README.md` and `GEMINI.md` files have been updated to include a comprehensive list of all source files.
    *   An image of the model is now included in `README.md`.
*   **Workflow:**
    *   The `workflow.ps1` script now automatically generates the `artifacts/model.png` image used in the documentation.
*   **Model:**
    *   The `export_panel_name` variable in `model.scad` is now empty by default to prevent accidental exports.

### v9

*   **Model Parameterization:**
    *   The `corpus_width` has been changed from 800mm to 600mm, making the model more compact.
*   **Workflow Automation:**
    *   The `workflow.ps1` script has been enhanced to automate the entire export and conversion process.
    *   The export directory is now dynamically created based on the model's dimensions.
*   **Script Refactoring:**
    *   All PowerShell scripts have been refactored to use a new `CommonFunctions.psm1` module.
*   **Bug Fixes:**
    *   Fixed a bug in the bounding box calculation in `split_layers.py` for `ARC` entities.

### v8

*   **Model Parameterization:**
    *   The `corpus_width` has been changed from 800mm to 600mm, making the model more compact.
*   **Workflow Automation:**
    *   Added a new PowerShell script, `workflow.ps1`, to automate the entire export and conversion process, including CSV cut list generation, DXF/STL/SVG export, DXF layering, and DXF to DWG/PDF conversion.
    *   The export directory is now dynamically created based on the model's dimensions, allowing for multiple model configurations to coexist.

### v7

*   **DXF to PDF Conversion:**
    *   Added a new PowerShell script, `convert-dxf-to-pdf.ps1`, to automate the conversion of DXF files to PDF format using LibreCAD.
    *   The script is hardened against LibreCAD's unreliable exit code by verifying the existence of the output PDF file instead of checking the exit code.

### v6

*   **DXF to DWG Conversion:**
    *   The `split-layers-dxf.ps1` script has been enhanced to automatically convert layered DXF files to DWG format using the ODA File Converter in batch mode. This ensures silent and efficient conversion.

### v5

*   **Enhanced Hole Visualization in DXF Export:**
    *   The `split_layers.py` script now includes the Z-coordinate in the text annotations for side-drilled holes (holes where the Z-coordinate is non-zero), providing clearer manufacturing information.
    *   A small cross symbol is now added at the (X,Y) location of side-drilled holes on the `DRILL` layer in 2D panel projections, serving as a visual indicator to distinguish them from through-holes or face-drilled holes.

### v4

*   Added a `DIMENSION` layer to the DXF export for panel and hole dimensions.
*   The dimensioning logic is optimized to avoid overlapping lines and redundant information.
*   Dimension text is now placed above the dimension line with a background fill for better readability.

### v3

*   Corrected the 2D hole coordinate calculation for DXF export to fix issues with reflected coordinates.
*   All exported 2D panels are now translated to start at the (0,0) origin.
*   The `split_layers.py` script now adds a detailed "Hole Schedule" table to the `ANNOTATION` layer of the DXF files.
*   The Z-coordinate in the hole metadata now correctly distinguishes between perpendicular and edge-drilled holes.

### v2

*   The number of drawers is now configurable.
*   The drawer assembly has been fixed. The back panel of the drawer is now correctly positioned.
*   The model has been made more parametric.
*   Added 4mm pilot holes for confirmat screws to join the drawer components.
*   The file `prompt/model-v2.md` has been added to reflect the changes in the model.
*   Added handle holes to drawer fronts.
*   Added transparency to the model for better visualization.
*   Added pilot holes for drawer slides in the corpus sides.
*   Added a configurable exploded view to visualize the assembly.
*   Added an HDF back panel to the corpus.
*   Added a pedestal to the bottom of the corpus.
*   Added glass doors to the bookcase section.
*   Added a feature to generate a CSV cut list.
*   Replaced the batch script for CSV generation with a more robust PowerShell script.
*   Standardized all panel names to single-word strings (e.g., `CorpusSideLeft`) for consistency and easier use in scripts.
*   Updated the cut list to include CNC comments.
*   Added a CNC export workflow using PowerShell and Python scripts to generate layered DXF files.
*   Fixed SVG export for panels with non-through holes by ensuring the holed face is on the `z=0` plane during projection.
*   Added a PowerShell script `split-layers-dxf.ps1` to automate the layering of DXF files.
*   Added a Python script `analyze_dxf.py` to analyze the layers in the generated DXF files.
*   Removed in-model text annotations for hole dimensions and locations to speed up DXF export.
*   The `split_layers.py` script now adds annotations to the DXF files based on the hole metadata exported from OpenSCAD.
*   Added a hole metadata export feature to generate CSV files with hole locations, which are then used to create annotations in the DXF files.

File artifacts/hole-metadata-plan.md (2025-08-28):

### Plan to Add Hole Metadata and Annotations

1.  **`model.scad` - Expose Hole Metadata**
    *   A new global variable `hole_metadata` will be created to store information about each hole (panel name, hole name, coordinates, diameter, depth).
    *   A function `log_hole()` will be implemented to populate this `hole_metadata` array.
    *   The existing modules that create holes will be modified to call `log_hole()`.
    *   When a panel is exported, the script will echo the collected `hole_metadata` to the console in a machine-readable format (pipe-delimited). This will be triggered by the `export_panel_name` variable not being empty.

2.  **`export-panels.ps1` - Capture and Persist Metadata**
    *   The script will be updated to capture the console output from OpenSCAD during the DXF export process.
    *   It will parse this output to extract the hole metadata table.
    *   For each panel, a corresponding CSV file (e.g., `CorpusSideLeft.csv`) will be created in the `artifacts/export/dxf-raw` directory. This file will contain the hole metadata for that specific panel.

3.  **`split_layers.py` - Generate DXF Annotations**
    *   The Python script will be modified to look for a companion CSV file for each DXF file it processes.
    *   If a CSV file is found, the script will:
        *   Read the hole data from the CSV.
        *   Create a new layer in the DXF file named `ANNOTATION`.
        *   For each hole, it will add a text annotation on the `ANNOTATION` layer at the specified X and Y coordinates. The annotation text will display the hole's diameter and depth (e.g., "D5 d10").

This approach avoids the limitations of OpenSCAD's text rendering for projections and leverages the existing scripting infrastructure to enrich the DXF files with manufacturing details.

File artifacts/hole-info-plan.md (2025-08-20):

### Plan

1.  **Extract Hole Information from OpenSCAD:**
    *   I will modify the `model.scad` file to generate a companion data file (e.g., in JSON format) for each panel that is exported.
    *   This data file will contain detailed information about each hole on the panel, including its location (x, y coordinates), diameter, and depth. This is necessary because the 2D DXF export from OpenSCAD doesn't retain depth information for holes.

2.  **Enhance the DXF Processing Script:**
    *   I will update the `split_layers.py` script, which already processes the exported DXF files.
    *   I will add functionality to this script to read the new hole data files.
    *   Using this data, the script will add the required annotations to the DXF files:
        *   A legend explaining the symbols or text used for different hole types.
        *   Dimension lines and text labels for each hole, indicating its location, diameter, and depth (e.g., "∅ 5mm, 10mm deep").

3.  **Integrate into the Export Workflow:**
    *   I will ensure the updated scripts work together seamlessly within the existing `export-panels.ps1` workflow.

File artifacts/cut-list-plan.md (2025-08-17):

### Plan for Generating the Cut List (Updated)

This plan outlines the steps to create a CSV cut list for all the panels required to build the chest of drawers, with "premium finish" edge banding. It also considers the use of OpenSCAD to generate the CSV file directly.

#### 1. Material and Panel Identification

The materials and panels are the same as in the previous plan.

*   **MEL-19:** 19mm Melamine (`melanine_thickness_main`)
*   **MEL-12:** 12mm Melamine (`melanine_thickness_secondary`)
*   **HDF-3:** 3mm HDF (`hdf_thickness`)

#### 2. Panel Analysis (Premium Edge Banding)

The dimensions and quantities remain the same, but the edge banding requirements are updated for a premium finish.

**Assumption for Wood Grain:** Dimension A is assumed to be along the height for vertical panels and along the width for horizontal panels.

**Edge Banding Notation:**
*   `1`: Edge banding required
*   `0`: No edge banding

---

**Component: Corpus**

| Panel Name | Panel Description | Count | Dimension A (grain) | Dimension B | Material | A-1 | A-2 | B-1 | B-2 |
| :--- | :--- | :---: | :--- | :--- | :--- | :-: | :-: | :-: | :-: |
| CorpusSide | Vertical side panel of the main body | 2 | `corpus_height` | `corpus_depth` | MEL-19 |  1  |  1  |  1  |  0  |
| CorpusTopBottom | Horizontal top and bottom panels | 2 | `corpus_width - 2*melanine_thickness_main`  | `corpus_depth` | MEL-19 |  1  |  0  |  0  |  0  |
| CorpusMiddle | Horizontal shelf separating drawers and bookcase | 1 | `corpus_width - 2*melanine_thickness_main`  | `corpus_depth` | MEL-19 |  1  |  0  |  0  |  0  |

**Component: Drawers (for each of the 6 drawers)**

| Panel Name | Panel Description | Count | Dimension A (grain) | Dimension B | Material | A-1 | A-2 | B-1 | B-2 |
| :--- | :--- | :---: | :--- | :--- | :--- | :-: | :-: | :-: | :-: |
| DrawerSide | Vertical side panel of a drawer  |  12 | `drawer_height` | `drawer_depth` | MEL-12 |  1  |  1  |  0  |  1  |
| DrawerBack | Vertical back panel of a drawer  | 6 | `drawer_body_width` | `drawer_height` | MEL-12 |  1  |  1  |  0  |  0  |
| DrawerBottom | Bottom panel of a drawer | 6 | `drawer_body_width` | `drawer_depth - melanine_thickness_secondary` | MEL-12 |  0  |  0  |  0  |  0  |

**Component: Drawer Fronts**

| Panel Name | Panel Description | Count | Dimension A (grain) | Dimension B | Material | A-1 | A-2 | B-1 | B-2 |
| :--- | :--- | :---: | :--- | :--- | :--- | :-: | :-: | :-: | :-: |
| DrawerFrontFirst | Front panel for the bottom drawer | 1 | `front_width` | `front_height_first` | MEL-19 |  1  |  1  |  1  |  1  |
| DrawerFrontStandard | Front panel for the middle 4 drawers | 4 | `front_width` | `front_height_standard` | MEL-19 |  1  |  1  |  1  |  1  |
| DrawerFrontTop | Front panel for the top drawer | 1 | `front_width` | `front_height_top` | MEL-19 |  1  |  1  |  1  |  1  |

**Component: Bookcase**

| Panel Name | Panel Description | Count | Dimension A (grain) | Dimension B | Material | A-1 | A-2 | B-1 | B-2 |
| :--- | :--- | :---: | :--- | :--- | :--- | :-: | :-: | :-: | :-: |
| Shelf | Shelf in the bookcase section  | 2 | `shelf_width` | `shelf_depth` | MEL-19 |  1  |  0  |  0  |  0  |

**Component: Pedestal**

| Panel Name | Panel Description | Count | Dimension A (grain) | Dimension B | Material | A-1 | A-2 | B-1 | B-2 |
| :--- | :--- | :---: | :--- | :--- | :--- | :-: | :-: | :-: | :-: |
| PedestalFrontBack | Front and back panels of the pedestal | 2 | `corpus_width - 2 * melanine_thickness_main` | `pedestal_height` | MEL-19 |  1  |  0  |  0  |  0  |
| PedestalSide | Side panels of the pedestal | 2 | `corpus_depth` | `pedestal_height` | MEL-19 |  1  |  0  |  0  |  0  |

**Component: Back Panel**

| Panel Name | Panel Description | Count | Dimension A (grain) | Dimension B | Material | A-1 | A-2 | B-1 | B-2 |
| :--- | :--- | :---: | :--- | :--- | :--- | :-: | :-: | :-: | :-: |
| HDFBackPanel | The back panel of the entire unit | 1 | `corpus_height` | `corpus_width` | HDF-3 |  0  |  0  |  0  |  0  |

---

#### 3. CSV Generation using OpenSCAD

It is possible to generate the CSV file directly from OpenSCAD. This approach has the advantage that the cut list is always in sync with the model parameters.

**Plan for OpenSCAD CSV Generation:**

1.  **Create a `generate_cut_list` module:** A new module, for example `generate_cut_list()`, will be created in the `model.scad` file. This module will not generate any 3D geometry.
2.  **Use a control flag:** The execution of this module will be controlled by a new boolean variable, e.g., `generate_cut_list_csv = false;`. When set to `true`, the cut list will be printed to the OpenSCAD console.
3.  **Use `echo()` to print CSV data:** The `echo()` command will be used to print the CSV data to the console.
    *   First, print the CSV header row.
    *   Then, for each panel in the analysis table, print a formatted string with the values separated by commas.
4.  **Structure the module:** The module will be organized by component (corpus, drawers, etc.) to make it easy to read and maintain.
5.  **Redirecting Console Output:** To save the CSV file, the user will need to render the model from the command line and redirect the standard output to a `.csv` file. For example:
    ```bash
    openscad -o model.stl -D generate_cut_list_csv=true model.scad > cut_list.csv
    ```
    (The `-o model.stl` is just to trigger the rendering, the important part is the output redirection).

#### 4. Assumptions and Considerations

*   **Wood Grain, Kerf, and Glass Doors:** The same considerations as in the previous plan apply.
*   **OpenSCAD Version:** This approach assumes a version of OpenSCAD that supports the `echo()` command and command-line execution.
*   **Complexity:** While generating the CSV from OpenSCAD is possible, it can make the `.scad` file more complex. The logic for generating the cut list will be mixed with the 3D modeling code.

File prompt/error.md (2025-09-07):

python : Traceback (most recent call last):
At line:1 char:1
+ python C:\Users\Tata\dev\chest-of-drawers-bookcase\split_layers.py C: ...
+ ~~~~~~~~~~~~~~~~~~~~~~~~~~~~~~~~~~~~~~~~~~~~~~~~~~~~~~~~~~~~~~~~~~~~~
    + CategoryInfo          : NotSpecified: (Traceback (most recent call last)::String  
   ) [], RemoteException
    + FullyQualifiedErrorId : NativeCommandError

  File "C:\Users\Tata\dev\chest-of-drawers-bookcase\split_layers.py", line 828, in <mod 
ule>
    main()
    ~~~~^^
  File "C:\Users\Tata\dev\chest-of-drawers-bookcase\split_layers.py", line 825, in main 
    split_layers(input_file, output_file)
    ~~~~~~~~~~~~^^^^^^^^^^^^^^^^^^^^^^^^^
  File "C:\Users\Tata\dev\chest-of-drawers-bookcase\split_layers.py", line 714, in spli 
t_layers
    add_title(msp, panel_name, final_bbox_before_title)
    ~~~~~~~~~^^^^^^^^^^^^^^^^^^^^^^^^^^^^^^^^^^^^^^^^^^
  File "C:\Users\Tata\dev\chest-of-drawers-bookcase\split_layers.py", line 577, in add_ 
title
    text.set_pos((title_x, title_y), align='MIDDLE_CENTER')
    ^^^^^^^^^^^^
AttributeError: 'Text' object has no attribute 'set_pos'
PS C:\Users\Tata\dev\chest-of-drawers-bookcase>

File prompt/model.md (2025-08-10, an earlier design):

Generate OpenSCAD code for a chest of drawers with integrated bookcase. Put the code in a file named model.scad.

These are the main dimensions from which all other dimensions are derived:

Corpus
H = 230 cm
W = 80 cm
D = 23 cm

Melanine material thickness
T1 = 19 mm
T2 = 12 mm

Shelves
Pw = W - 2*T1
Ph = D

Slides
Sw = 200 mm
Sh = 45 mm
Sd = 13 mm

Drawers
Dh = 20 cm
DBh = Dh - T2
Dd = D - 0.5 cm
Dw = Pw - 2*Sd
DBw = Dw - 2*T2
Doffset = 1 cm
Doffset2 = 1 cm

Drawer Fronts
Gap = 3 mm
Overhang = 3 mm
Margin = 1.5 mm
Fw = W - 2 * Margin
Fh0 = Dh + Doffset - Gap
F1h = T1 + Fh0
Fh = Fh0
F6h = Fh + Overhang

The material is T1 thick melanine for the corpus and bookshelves.

The drawer fronts are also T1 thick melanine.

The drawer corpus is made out of T2 melanine.

The whole is structured as follows:

Corpus
- The corpus consists of two sides and the top, the bottom and the middle plates.
- The corpus is H tall, W wide and D deep.
- The two sides are H tall and D wide and made out of T1 melanine.
- The top, bottom and three shelves are W-2*T1 tall and D wide.
- The middle plate divides the corpus into two compartments.
- The bottom compartment contains only drawers.
- The top compartment is split into three parts by two shelves.

Drawers
- Each drawer is mounted to the sides of the corpus by the way of slides.
- There are two slides per drawer, a left one and a right one.
- A slide is Sw wide, Sh tall and Sd deep.
- Looking from left to right there is the left side panel of thickness T1, then the left slide of thickness Sd, then the drawer Dw wide and Dh heigh, the right slide of thickness Sd and the right side panel of thickness T1. 
- There will be six drawers starting at the bottom.
- The lowest drawer starts at Doffset from the bottom plate of the corpus.
- The bottom of each subsequent drawer body is positioned Dh + Doffset2 above the bottom of the previous one (i.e., y_bottom_body[i+1] = y_bottom_body[i] + Dh + Doffset2).
- The middle plate sits Doffset2 higher than the top of the last drawer and forms a shelf.
- Each drawer consists of four plates:
- - The drawer's back plate is DBh tall and DBw wide.
- - The two side plates are Dh tall and Dd wide.
- - The drawer's bottom plate is Dd tall and DBw wide.
- - The drawer's sides are screwed to the drawer's bottom plate and to the back plate with comfirmat screws phi 5 mm.
- - The drawer's bottom plate sits between the two side plates.
- - The back plate sits on top of the bottom plate and is screwed to the side plates only (with confirmat screws phi 5 mm).

Drawer Fronts
- The design intends for a constant Gap between the visible fronts.
- The first drawer front is taller to account for the overlap T1 with the bottom plate of the corpus.
- The last drawer front is also taller to account for the smaller overlap with the middle plate of the corpus.
- Drawers two to six have Overhang below the bottom of the drawer.
- The first, lowest drawer front is Fw wide and F1h tall.
- The last, the sixth drawer front is Fw wide and F6h tall.
- The middle drawer fronts are Fw wide and Fh tall.

Shelves
- The top compartment is split into three parts by two shelves.
- Each shelf plate is Pw wide and Ph tall.

Joinery
Confirmat screws phi 5 mm are used to join corpus panels and drawer panels.
The front pannels are joined with wooden dowels (phi 6 mm by 30 mm length) to the drawer box (to the side panels and the bottom panel).
The dowels stick 1 cm deep into the drawer front and the rest is in the drawer box.
Make appropriate holes for dowels in drawer fronts, sides and bottom.
Make appropriate hole for confirmat screws in corpus sides, top, middle and bottom plates, and shelves too.
Make appropriate hole for confirmat screws in drawer sides, back plate and bottom plate.

Make every component as a OpenSCAD module, starting from the corpus down to the joinery.

Paint different types of components in a vivid and distinct color so that components can be easily distinguished one form another in the preview.

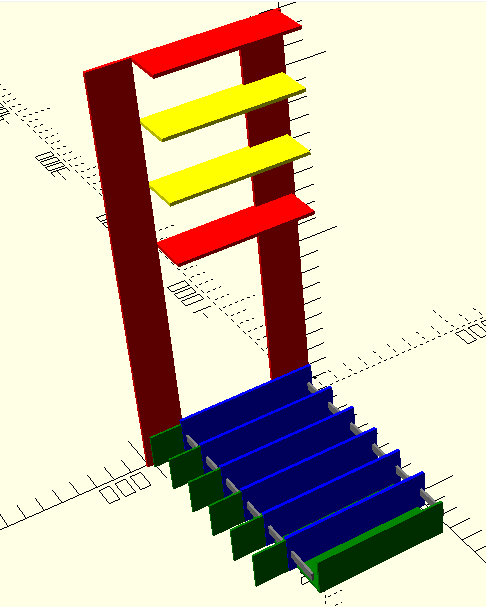
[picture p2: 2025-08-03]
artifacts/error-01.png

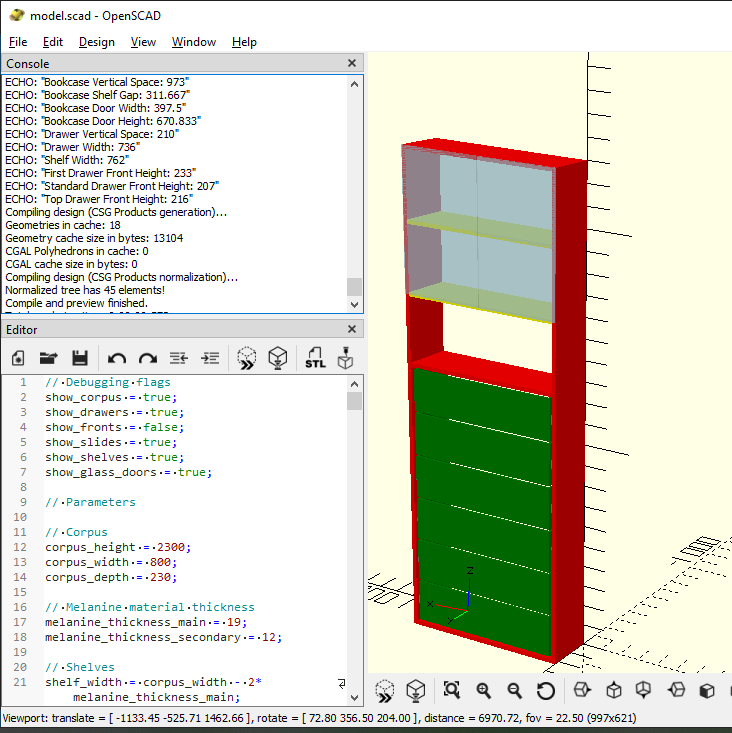
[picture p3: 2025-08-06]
artifacts/drawer-back-panel-location-error.png

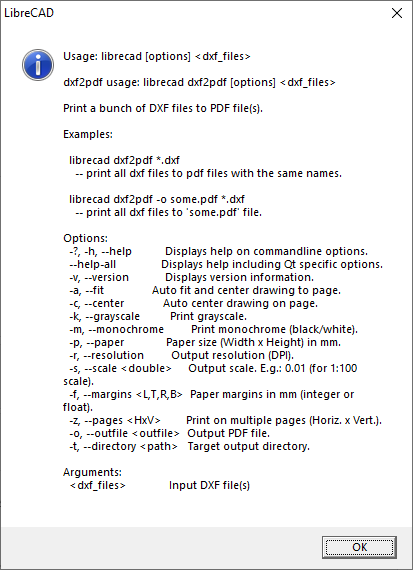
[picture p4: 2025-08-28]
artifacts/LibreCAD_dxf2pdf_options.png

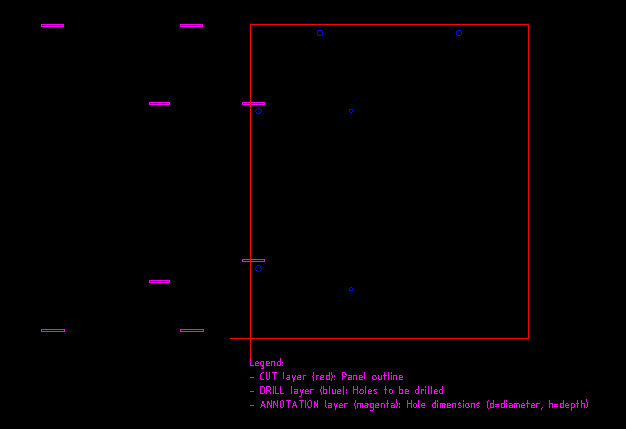
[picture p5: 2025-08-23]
artifacts/screenshot/DrawerSideLeft.png

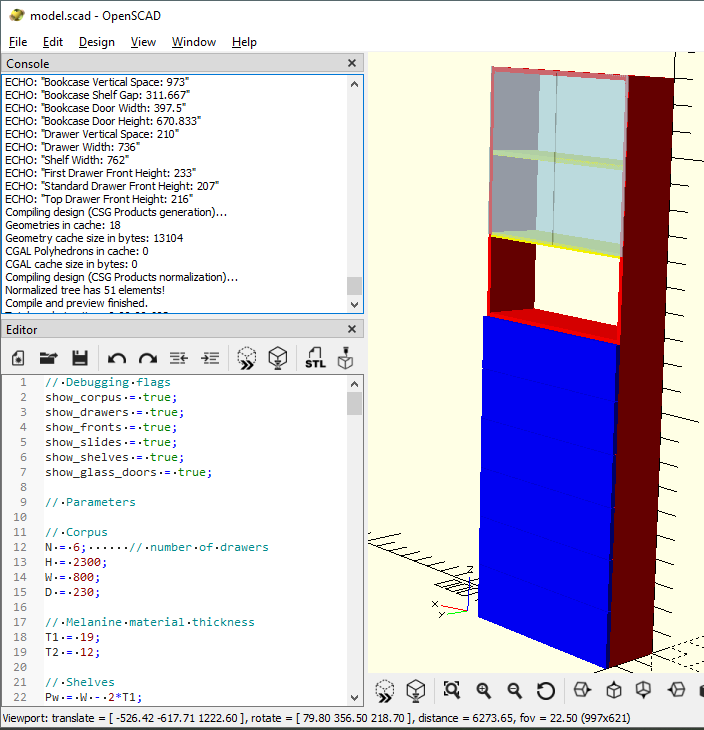
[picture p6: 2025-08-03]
artifacts/chest-of-drawers-bookcase-openscad.png

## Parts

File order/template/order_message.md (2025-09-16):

# Ormar sa ladicama i policama za knjige

Molim vas ponudu prema narudžbi u prilogu.

Narudžba se sastoji od panela za korpus ormara (iveral 18mm) i panela za ladice (iveral 12 mm). 

Korpus i ladice koriste spajanje panela pomoću konfirmat vijaka i zahtijevaju CNC bušenje rupa fi 4mm za konfirmat vijke. U tu svrhu koriste se dvije vrste rupa: rupe koje prolaze kroz panel i rubne rupe za prihvat vijka. 

Fronte ladica spajaju se pomoću drvenih tipala dimenzija fi 6mm x 30mm. Fronte ladica zahtijevaju CNC bušenje slijepih rupa fi 6m dubine 10mm. Paneli ladica zahtijevaju CNC bušenje rubnih prihvatnih rupa za drvene tiple fi 6mm dubine 30mm.

Bočni paneli korpusa ormara i bočni paneli ladica zahtijevaju CNC bušenje pilot rupa fi 2.5mm dubine 2mm za montažu kliznih vodilica.

Pozicije i dimenzije svih rupa nalaze se na priloženim DWG datotekama, kao i na priloženim PDF skicama.

Srdačan pozdrav,

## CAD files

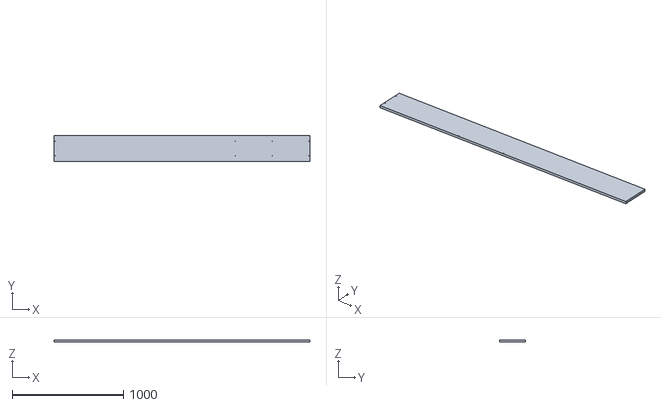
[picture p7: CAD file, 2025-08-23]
artifacts/export/stl/CorpusSideRight.stl
2300.0 x 230.0 x 19.0

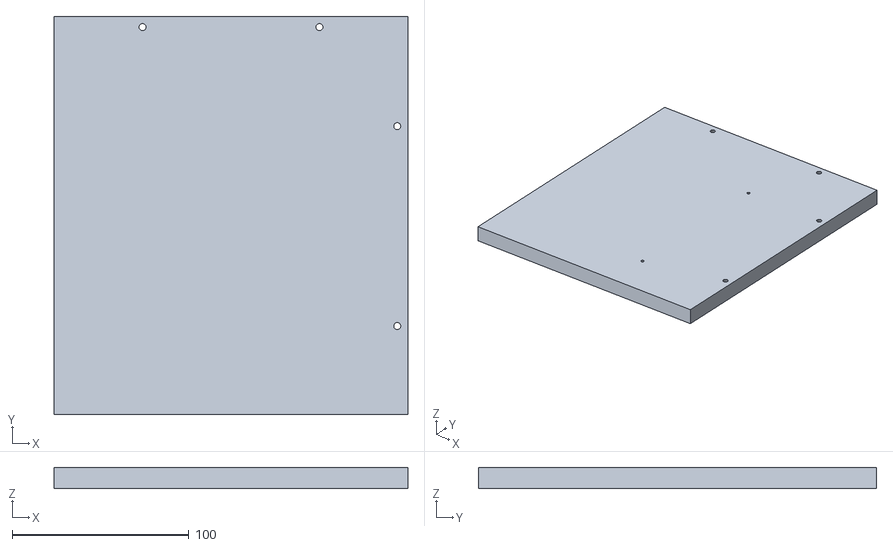
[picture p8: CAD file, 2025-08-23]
artifacts/export/stl/DrawerSideRight.stl
200.0 x 225.0 x 12.0

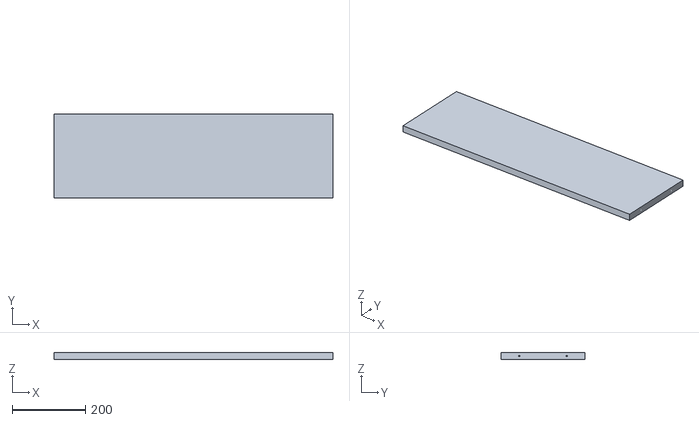
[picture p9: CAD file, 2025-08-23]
artifacts/export/stl/CorpusTopBottom.stl
762.0 x 230.0 x 19.0

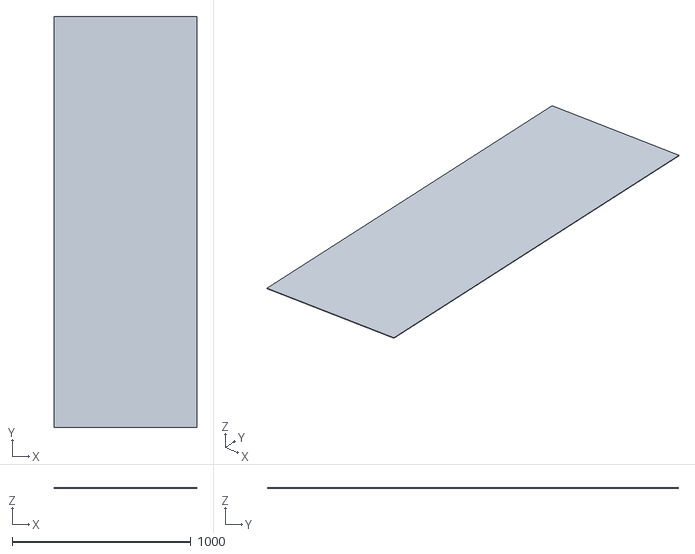
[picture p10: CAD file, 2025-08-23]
artifacts/export/stl/HDFBackPanel.stl
800.0 x 2300.0 x 3.00

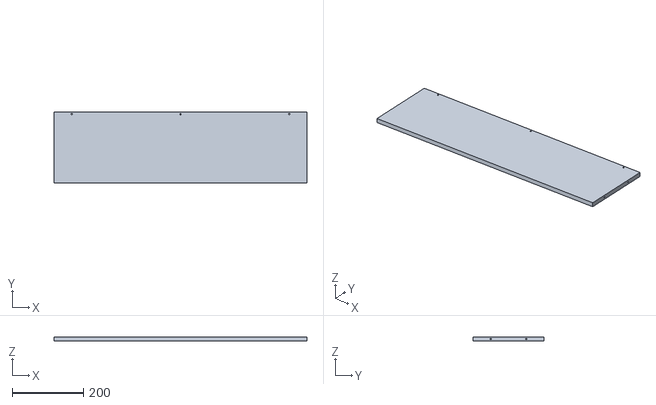
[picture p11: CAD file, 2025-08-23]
artifacts/export/stl/DrawerBack.stl
712.0 x 200.0 x 12.0

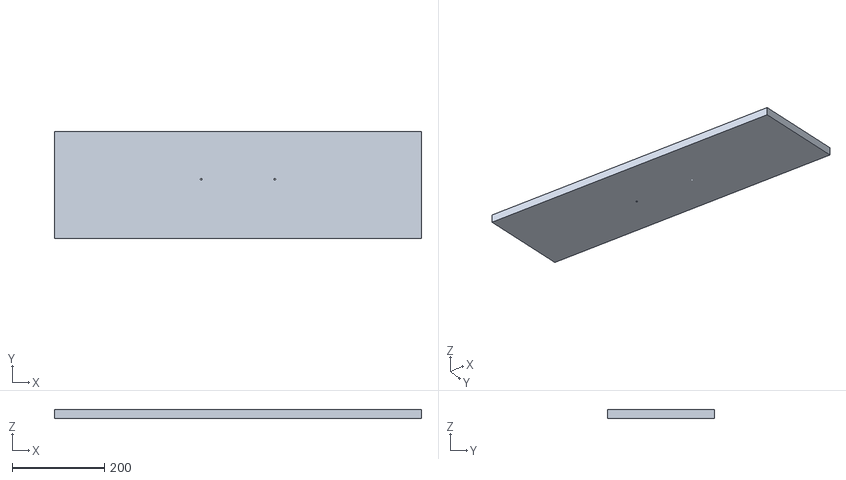
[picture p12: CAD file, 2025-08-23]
artifacts/export/stl/DrawerFrontFirst.stl
797.0 x 233.0 x 19.0

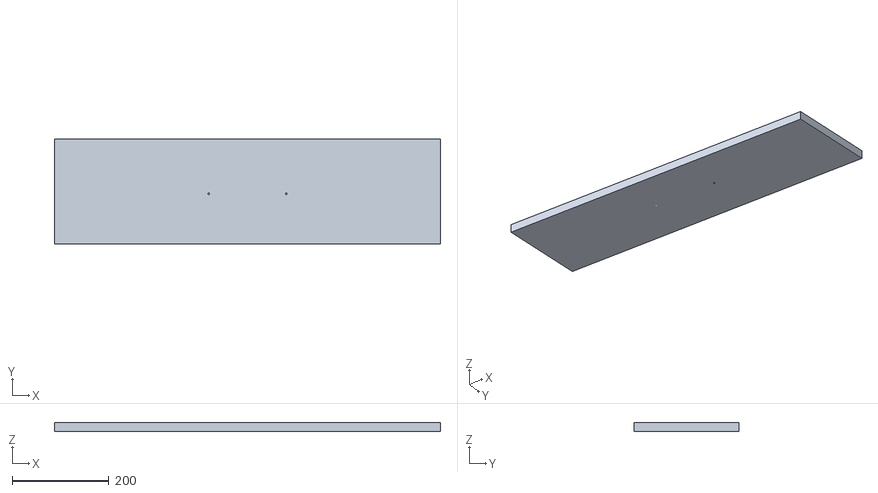
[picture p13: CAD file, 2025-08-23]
artifacts/export/stl/DrawerFrontTop.stl
797.0 x 216.0 x 19.0

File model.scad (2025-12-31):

// Chest of Drawers with Integrated Bookcase
// The coordinate origin is at the lower left front of the corpus.
// The y-direction increases into the corpus body.
// This means that drawer fronts and glass doors will have y-origin in the negative direction.

FN = 16;

// Trace string to console
show_trace = false;

// Cut List Generation
generate_model_identifier = false;
generate_cut_list_csv = false;
generate_panel_names_list = false;

// DXF Export: Set the panel name to export, e.g., "CorpusSideLeft"
// Panel selector (via -D name="...")
// See the 'export_panel' module for a list of all panel names.
export_panel_name = "CorpusShelfTemplate";
export_type = "dxf";  // "dxf"|"stl"|"svg"

panel_names = ["CorpusSideLeft", "CorpusSideRight", "CorpusTopBottom", "CorpusMiddle", "DrawerSideLeft", "DrawerSideRight", "DrawerBack", "DrawerBottom", "DrawerFrontBottom", "DrawerFrontStandard", "DrawerFrontTop", "Shelf", "PedestalFrontBack", "PedestalSide", "HDFBackPanel", "CorpusSideSlideTemplate", "DrawerFrontInsideTemplate", "DrawerFrontOutsideTemplate", "CorpusShelfTemplate", "PedestalSideTemplate", "DrawerBackTemplate", "DrawerSideTemplate"];

// Transparency
part_alpha = 0.4;

// Debugging flags
show_corpus = true;
show_corpus_sides = true;
show_drawers = true;
show_fronts = true;
show_slides = true;
show_shelves = true;
show_glass_doors = true;
show_hdf_back_panel = true;
show_pedestal = true;


// Exploded View Parameters
exploded_view = false; // Set to true to enable exploded view
explosion_factor = 2; // Scale factor for explosion distance

// Parameters

// Corpus
corpus_height = 2300;
corpus_width = 600;
corpus_depth = 230;

// Melanine material thickness
melanine_thickness_main = 18;
melanine_thickness_secondary = 10;

model_identifier = str("H",corpus_height,"xW",corpus_width,"xD",corpus_depth,"_Mm",melanine_thickness_main,"_Ms",melanine_thickness_secondary);

// HDF Back Panel
hdf_thickness = 3;

// Pedestal
pedestal_height = 30;

// Geometric Constants
ROT_X_90 = [90, 0, 0];
ROT_X_NEG_90 = [-90, 0, 0];
ROT_Y_90 = [0, 90, 0];
ROT_Y_NEG_90 = [0, -90, 0];
ROT_Z_90 = [0, 0, 90];
ROT_Z_NEG_90 = [0, 0, -90];
ROT_NONE = [0, 0, 0];

// Joinery
confirmat_screw_length = 49;
confirmat_hole_diameter = 4;
confirmat_hole_radius = confirmat_hole_diameter / 2;
confirmat_hole_edge_distance = 50;

// Dowels
dowel_diameter = 6;
dowel_radius = dowel_diameter / 2;
dowel_length = 30;
dowel_hole_depth_in_front = 10;
dowel_hole_edge_distance = 50;
panel_length_for_four_dowels = 500;

// Shelves
shelf_width = corpus_width - 2*melanine_thickness_main;
shelf_depth = corpus_depth;

// Slides
slide_width = 200;
slide_height = 45;
slide_depth = 13;
slide_z_offset = 50;

// Slide Pilot Holes
slide_pilot_hole_depth = 2;
slide_pilot_hole_diameter = 2.5;
slide_pilot_hole_radius = slide_pilot_hole_diameter / 2;
drawer_slide_pilot_hole_offsets = [37, 163];
corpus_slide_pilot_hole_offsets = [6.5, 35, 51, 76, 99, 115];

// Drawers
number_of_drawers = 6;
drawer_height = 200;
drawer_body_height = drawer_height - melanine_thickness_secondary;
drawer_depth = corpus_depth - 5;
drawer_width = shelf_width - 2*slide_depth;
drawer_body_width = drawer_width - 2*melanine_thickness_secondary;
drawer_bottom_offset = 10;     // the lowest drawer offset from the corpus bottom
drawer_gap = 10;    // the gap between drawers
drawer_vertical_space = drawer_height + drawer_gap;    // vertical space between drawers
drawer_origin_z = melanine_thickness_main + drawer_bottom_offset;     // offset of the bottom of the first drawer

// Middle Plate
middle_plate_z = drawer_origin_z + number_of_drawers*drawer_vertical_space;

// Drawer Fronts
front_gap = 3;
front_overhang = 3;
front_margin = 1.5; // margin on left and right side of drawer front
front_width = corpus_width - 2 * front_margin;
front_depth = melanine_thickness_main;
front_height_base = drawer_height + drawer_gap - front_gap;
front_height_first = melanine_thickness_main + drawer_bottom_offset - front_gap + front_height_base;
front_height_standard = front_height_base;
front_height_top = front_height_standard + 3*front_overhang;
handle_hole_diameter = 4;
handle_hole_spacing = 160;



// Bookcase dimensions
bookcase_start_z = middle_plate_z + melanine_thickness_main;
bookcase_end_z = corpus_height - melanine_thickness_main;
bookcase_height = bookcase_end_z - bookcase_start_z;
bookcase_shelf_gap = (bookcase_height - 2 * melanine_thickness_main) / 3;

// Bookcase glass doors
bookcase_glass_door_width = (corpus_width - (1 + front_gap + 1))/2;
bookcase_glass_door_height = melanine_thickness_main + bookcase_shelf_gap + melanine_thickness_main + bookcase_shelf_gap + melanine_thickness_main/2;
bookcase_glass_door_tickness = 4;

// Trace string to console
module T(s) {
    if (show_trace) {
        echo(s);
    }
}

// Derived Measurements & Debugging
T(str("Middle Plate Z: ", middle_plate_z));
T(str("Bookcase Vertical Space: ", bookcase_height));
T(str("Bookcase Shelf Gap: ", bookcase_shelf_gap));
T(str("Bookcase Door Width: ", bookcase_glass_door_width));
T(str("Bookcase Door Height: ", bookcase_glass_door_height));
T(str("Drawer Vertical Space: ", drawer_vertical_space));
T(str("Drawer Width: ", drawer_width));
T(str("Shelf Width: ", shelf_width));
T(str("First Drawer Front Height: ", front_height_first));
T(str("Standard Drawer Front Height: ", front_height_standard));
T(str("Top Drawer Front Height: ", front_height_top));

// Colors
color_corpus = "Red";
color_drawers = "Green";
color_drawer_back = "LightGreen";
color_fronts = "Blue";
color_shelves = "Yellow";
color_slides = "Gray";
color_joinery = "Black";
color_glass = "LightBlue";
color_hdf_panel = "White";
color_pedestal = "SaddleBrown";
color_annotation = "Magenta";

// The exported DXF will contain two layers: "CUT" for the panel outline and "DRILL" for the holes.
// Note: The dxf_layer module is a convention and might not be supported by all OpenSCAD versions or tools.

CUT = "red";
DRILL = "blue";


module dxf_layer(layer_name) {
    if (export_panel_name != "") {
        color(layer_name) children();
    } else {
        children();
    }
}

module explode(component_center) {
    if (exploded_view) {
        corpus_center = [corpus_width/2, corpus_depth/2, corpus_height/2];
        translate((component_center - corpus_center) * explosion_factor) children();
    } else {
        children();
    }
}

module confirmat_hole_side() {
    cylinder(h=melanine_thickness_main, r=confirmat_hole_radius, $fn=FN, center=true);
}

module confirmat_hole_plate() {
    cylinder(h=confirmat_screw_length-melanine_thickness_main, r=confirmat_hole_radius, $fn=FN);
}

module dowel_hole(height) {
    cylinder(h=height, r=dowel_radius, $fn=FN);
}

module drawer_confirmat_hole() {
    cylinder(h=melanine_thickness_secondary, r=confirmat_hole_radius, $fn=FN, center=true);
}

module drawer_confirmat_hole_threaded() {
    cylinder(h=confirmat_screw_length-melanine_thickness_secondary, r=confirmat_hole_radius, $fn=FN);
}

module handle_hole() {
    cylinder(h=melanine_thickness_main, r=handle_hole_diameter/2, $fn=FN, center=true);
}

module slide_pilot_hole() {
    cylinder(h=slide_pilot_hole_depth, r=slide_pilot_hole_radius, $fn=FN);
}

// --- Hole Metadata Export ---

function get_corpus_side_hole_2d_coords(x, y, z, is_left) = is_left ? [-z + corpus_height, y] : [z, y];
function get_drawer_side_hole_2d_coords(x, y, z, is_left) = is_left ? [drawer_depth - y, z] : [y, z];
function get_drawer_back_hole_2d_coords(x, y, z) = [x, z];
function get_drawer_bottom_hole_2d_coords(x, y, z) = [x, y];
function get_drawer_front_hole_2d_coords(x, y, z) = [x, z];
function get_shelf_hole_2d_coords(x, y, z) = [x, y];
function get_pedestal_front_back_hole_2d_coords(x, y, z) = [x, -z + pedestal_height];
function get_pedestal_side_hole_2d_coords(x, y, z) = [z, y];
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

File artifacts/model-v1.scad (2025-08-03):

// Generated by Gemini
// Chest of Drawers with Integrated Bookcase

// --- DEBUGGING FLAGS ---
show_corpus = true;
show_drawers = true;
show_slides = true;
show_joinery = true;

// --- MAIN DIMENSIONS ---
// Corpus
H = 2300; // 230 cm
W = 800;  // 80 cm
D = 230;  // 23 cm

// Material Thickness
T1 = 19;
T2 = 12;

// Slides
Sw = 200;
Sh = 45;
Sd = 13;

// Drawers
Dh = 200; // 20 cm
Doffset = 10; // 1 cm
Doffset2 = 10; // 1 cm

// Drawer Fronts
Gap = 3;
Overhang = 3;

// Joinery
confirmat_diam = 5;
dowel_diam = 6;
dowel_len = 30;
dowel_front_depth = 10;

// --- DERIVED DIMENSIONS ---
// Corpus & Shelves
Pw = W - 2 * T1;
Ph = D;

// Drawers
DBh = Dh - T2;      // Drawer back plate height
Dd = D - 5;         // Drawer side plate depth (D - 0.5cm)
Dw = Pw - 2 * Sd;   // Drawer body width
DBw = Dw - 2 * T2;  // Drawer bottom/back inner width

// Drawer Fronts
Fw = W;
Fh0 = Dh + Doffset2 - Gap;
F1h = T1 + Fh0;
Fh = Overhang + Fh0;
F6h = Fh + Overhang;

// --- CALCULATED POSITIONS ---
// Y-position of the bottom of each drawer body
drawer_y_pos = [ for (i = [0:5]) T1 + Doffset + i * (Dh + Doffset2) ];

// Y-position of the middle plate (shelf above drawers)
middle_plate_y = drawer_y_pos[5] + Dh + Doffset2;

// Bookcase dimensions
bookcase_start_y = middle_plate_y + T1;
bookcase_end_y = H - T1;
bookcase_h = bookcase_end_y - bookcase_start_y;
bookcase_shelf_gap = (bookcase_h - 2 * T1) / 3;

// Y-positions of the two bookcase shelves
bookcase_shelf1_y = bookcase_start_y + bookcase_shelf_gap;
bookcase_shelf2_y = bookcase_start_y + 2 * bookcase_shelf_gap + T1;

// --- HELPER MODULES ---
module confirmat_hole(l, d=confirmat_diam) {
    cylinder(h=l, d=d, center=true);
}

module dowel_hole(l, d=dowel_diam) {
    cylinder(h=l, d=d, center=true);
}

// --- COMPONENT MODULES ---

// Slide representation
module slide() {
    color("darkgrey")
    cube([Sd, Sw, Sh]);
}

// Drawer Box (sides, back, bottom)
module drawer_box() {
    difference() {
        union() {
            // Left Side Plate
            translate([0, 0, 0])
            cube([T2, Dd, Dh]);
            
            // Right Side Plate
            translate([Dw - T2, 0, 0])
            cube([T2, Dd, Dh]);
            
            // Bottom Plate (between sides)
            translate([T2, 0, 0])
            cube([DBw, Dd, T2]);
            
            // Back Plate (between sides, on top of bottom)
            translate([T2, Dd - T2, T2])
            cube([DBw, T2, DBh]);
        }
        if (show_joinery) {
            // Holes for Confirmat Screws
            // Side-to-Bottom joinery (4 screws)
            for (x_pos = [T2/2, Dw - T2/2]) {
                for (y_pos = [Dd/4, Dd*3/4]) {
                    translate([x_pos, y_pos, T2/2]) rotate([90,0,0]) confirmat_hole(T2);
                }
            }
            // Side-to-Back joinery (4 screws)
            for (x_pos = [T2/2, Dw - T2/2]) {
                for (z_pos = [T2 + DBh/4, T2 + DBh*3/4]) {
                    translate([x_pos, Dd - T2/2, z_pos]) rotate([0,90,0]) confirmat_hole(T2);
                }
            }
            // Dowel holes from front
            dowel_box_depth = dowel_len - dowel_front_depth;
            // Dowels into side panels (4)
            for (x_pos = [T2/2, Dw-T2/2]) {
                 for (z_pos = [Dh/4, Dh*3/4]) {
                    translate([x_pos, -dowel_box_depth/2, z_pos]) rotate([0,90,0]) dowel_hole(dowel_box_depth);
                 }
            }
            // Dowels into bottom panel (2)
            for (x_pos = [Dw/3, Dw*2/3]) {
                translate([x_pos, -dowel_box_depth/2, T2/2]) rotate([0,90,0]) dowel_hole(dowel_box_depth);
            }
        }
    }
}

// Drawer Front
module drawer_front(f_h) {
    difference() {
        cube([Fw, T1, f_h]);
        if (show_joinery) {
            // Dowel holes
            // Dowels into side panels (4)
            for (x_pos = [T1 + Sd + T2/2, W - T1 - Sd - T2/2]) {
                 for (z_pos = [f_h/4, f_h*3/4]) {
                    translate([x_pos, T1-dowel_front_depth/2, z_pos]) rotate([0,90,0]) dowel_hole(dowel_front_depth);
                 }
            }
            // Dowels into bottom panel (2)
            for (x_pos = [W/3, W*2/3]) {
                translate([x_pos, T1-dowel_front_depth/2, (f_h - Dh)/2 + T2/2]) rotate([0,90,0]) dowel_hole(dowel_front_depth);
            }
        }
    }
}

// --- MAIN ASSEMBLY ---

// 1. Corpus
if (show_corpus) {
    color("SaddleBrown")
    difference() {
        union() {
            // Left Side
            translate([0, 0, 0]) cube([T1, D, H]);
            // Right Side
            translate([W - T1, 0, 0]) cube([T1, D, H]);
            // Bottom
            translate([T1, 0, 0]) cube([Pw, Ph, T1]);
            // Top
            translate([T1, 0, H - T1]) cube([Pw, Ph, T1]);
            // Middle Plate
            translate([T1, 0, middle_plate_y]) cube([Pw, Ph, T1]);
            // Bookcase Shelf 1
            translate([T1, 0, bookcase_shelf1_y]) cube([Pw, Ph, T1]);
            // Bookcase Shelf 2
            translate([T1, 0, bookcase_shelf2_y]) cube([Pw, Ph, T1]);
        }
        if (show_joinery) {
            // Corpus Confirmat Holes
            shelf_ys = [T1, middle_plate_y, bookcase_shelf1_y, bookcase_shelf2_y, H-T1];
            for (y_pos = shelf_ys) {
                for (x_pos = [T1/2, W-T1/2]) {
                    for (z_pos = [D/4, D*3/4]) {
                        translate([x_pos, z_pos, y_pos]) rotate([90,0,0]) confirmat_hole(T1);
                    }
                }
            }
        }
    }
}

// 2. Drawers and Slides
if (show_drawers) {
    for (i = [0:5]) {
        // Determine front height
        front_h = (i == 0) ? F1h : (i == 5) ? F6h : Fh;
        
        // Determine front y-position
        front_y = (i == 0) ? T1 : drawer_y_pos[i] - Overhang;

        // Assemble full drawer
        // Drawer Box
        translate([T1 + Sd, 0, drawer_y_pos[i]])
        color("SandyBrown")
        drawer_box();

        // Drawer Front
        translate([0, D - T1, front_y])
        color("LightGray")
        drawer_front(front_h);

        // Slides
        if (show_slides) {
            slide_y_pos = drawer_y_pos[i] + (Dh - Sh) / 2;
            // Left Slide
            translate([T1, (D - Sw) / 2, slide_y_pos])
            slide();
            // Right Slide
            translate([W - T1 - Sd, (D - Sw) / 2, slide_y_pos])
            slide();
        }
    }
}

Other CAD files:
artifacts/export/dxf-raw/PedestalFrontBack.dxf
artifacts/export/dxf-raw/DrawerBack.dxf
artifacts/export/dxf-raw/CorpusSideLeft.dxf
artifacts/export/dxf-raw/DrawerSideRight.dxf
artifacts/export/dxf-raw/HDFBackPanel.dxf
artifacts/export/dxf-raw/CorpusSideRight.dxf
artifacts/export/dxf-raw/DrawerFrontFirst.dxf
artifacts/export/stl/Shelf.stl
artifacts/export/dxf-raw/CorpusTopBottom.dxf
artifacts/export/stl/DrawerSideLeft.stl
artifacts/export/dxf-raw/DrawerBottom.dxf
artifacts/backup/model-with-text-annotations.scad
artifacts/export/dwg/CorpusMiddle.dwg
artifacts/export/dwg/CorpusSideLeft.dwg
artifacts/export/dwg/CorpusSideRight.dwg
artifacts/export/dwg/CorpusTopBottom.dwg
artifacts/export/dwg/DrawerBack.dwg
artifacts/export/dwg/DrawerBottom.dwg
artifacts/export/dwg/DrawerFrontFirst.dwg
artifacts/export/dwg/DrawerFrontStandard.dwg
artifacts/export/dwg/DrawerFrontTop.dwg
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

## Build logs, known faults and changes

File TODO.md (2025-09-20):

- [x] Corpus
- [x] Shelves
- [x] Corpus joinery (panels + shelves)
- [x] Drawers
- [x] Drawer fronts
- [x] Drawers joinery (box + fronts)
- [x] Handles joinery
- [x] Glass door
- [] Glass door joinery
- [x] Slides
- [x] Slides joinery
- [x] Cabinet's pedestal (base)
- [x] Create cutting list (CSV)
- [x] Add a DIMENSION layer to DXF file to hold panel dimensional information and hole positions for both through holes and side holes. The lines with arrows with a dimension value above the line.
- [x] Make side holes visible in the DXF file.
- [x] Export DWG file for all panels needing CNC operation (drill holes)
- [x] Convert DWG files to PDF files using LibreCAD in batch mode 
- [X] Add title to DXF drawings with the panel name and description.
- [X] Create template panels for:
    - drilling holes for the slide mount to the corpus side panel (TBD)
    - drilling holes for the slide mount to the drawer side panel (DrawerSideLeft)
    - drilling holes to the drawer corpus for the drawer front panel (TBD)
    - drilling holes to the drawer back panel (DrawerBack)
    - drilling holes for the top and bottom panels in the corpus side panels (TBD)
    - drilling holes in the pedestal sides (PedestalSide)

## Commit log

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2025-08-06 feat: Refine drawer construction and component positioning
    This commit introduces several improvements to the model's realism and construction details.
    - **Drawer Construction:** The drawer back panel has been repositioned to sit behind the drawer bottom plate, creating a stronger and more conventional drawer assembly.
    - **HDF Back Panel:** A 3mm HDF back panel has been added to the rear of the main corpus, enclosing the structure.
    - **Component Alignment:**
    - The drawer boxes and slides are now positioned to be flush with the front of the corpus for a more realistic fit.
    - The vertical position of the slides is now controlled by a new `slide_z_offset` parameter for easier adjustment.
    [model.scad]
2025-08-10 feat(drawers): Center drawer fronts and add margin
    This commit introduces two main improvements to the drawer fronts:
    1. Horizontal Centering: The drawer fronts are now correctly centered horizontally within the corpus. The front_margin parameter is used to create an equal gap on both the left and right sides, ensuring a visually balanced design.
    2. Configurable Margin: A front_margin parameter has been added to easily control the spacing between the drawer fronts and the corpus sides. This makes the design more flexible and easier to customize.
    The documentation in GEMINI.md, prompt/model-v2.md, and artifacts/conversation.md has been updated to reflect these changes.
    [model.scad]
2025-08-10 feat(corpus): Add parametric confirmat screw holes for assembly
    This commit adds pilot holes for the Confirmat screws used to assemble the main corpus, significantly improving the model's realism and manufacturability.
    Key changes:
    - Confirmat Screw Holes: 4mm pilot holes have been added to the corpus side panels, horizontal plates (top, bottom, middle), and shelves. This allows for precise and strong assembly using 4.8mm x 49m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
    - Parametric Control: The dimensions of the screw holes are now parametrically controlled. The following new variables have been introduced:
    - confirmat_screw_length
    - confirmat_hole_diameter
    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
    [model.scad]
2025-08-10 feat(drawers): Add confirmat screw holes to drawer assembly
    This commit introduces 4mm pilot holes for the 4.8mm x 49mm confirmat screws used to assemble the drawer boxes.
    The changes include:
    - Modifying the drawer_side, drawer_back, and drawer_bottom modules in model.scad to include the screw holes.
    - The number of screws is determined by the length of the panel edge (2 for <50cm, 3 for >=50cm).
    - Holes are positioned 5cm from the panel edges.
    The project documentation has been updated to reflect these changes.
    [model.scad]
2025-08-10 feat: Add wooden dowel joinery for drawer fronts
    This commit introduces wooden dowel joinery for attaching drawer fronts to the drawer box assembly.
    - Added 6mm diameter, 30mm long dowel holes to drawer fronts, sides, and bottom panels.
    - Implemented a 1cm blind hole depth in the drawer fronts.
    - Ensured dowel hole locations are 5cm from the edge.
    - Added logic for two dowels per panel per side if the panel length is less than 50cm, and four dowels if longer, with even spacing.
    - Corrected the rotation of dowel holes in `drawer_side` and `drawer_bottom` modules to be perpendicular to the panels.
    - Replaced the magic constant `500` with a descriptive constant `panel_length_for_four_dowels`.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
    [model.scad]
2025-08-12 feat: Add handle holes and transparency to model
    This commit introduces handle holes to drawer fronts and adds transparency for better visualization.
    - Added `handle_hole_diameter` and `handle_hole_spacing` parameters.
    - Implemented `handle_hole` module and integrated into `drawer_front`.
    - Added `part_alpha` for transparency and applied to various modules.
    - Updated `prompt/model-v2.md`, `GEMINI.md`, and `README.md` to document these changes.
    [model.scad]
2025-08-13 feat: Add pilot holes for drawer slides
    This commit introduces pilot holes in the drawer sides for attaching the drawer slides.
    - Added descriptive constants for pilot hole dimensions (depth, diameter, and distances).
    - Created a `slide_pilot_hole` module for the new holes.
    - Modified the `drawer_side` module to include the pilot holes on both left and right sides.
    - Updated documentation to reflect these changes.
    [model.scad]
2025-08-13 feat: Add corpus side pilot holes for drawer slides
    This commit introduces pilot holes in the corpus sides for fixing drawer slides.
    - Added common constants for pilot hole depth, diameter, and radius.
    - Introduced `corpus_slide_pilot_hole_offsets` array for corpus side holes.
    - Refactored drawer slide pilot holes to use `drawer_slide_pilot_hole_offsets` array.
    - Modified `corpus_side` module to include pilot holes for drawer slides.
    - Updated `corpus` module to correctly instantiate corpus sides.
    - Updated `drawer_side` module to use array for drawer slide pilot hole offsets.
    - Updated documentation (`model-v2.md`, `GEMINI.md`, `README.md`) to reflect these changes.
    [model.scad]
2025-08-14 feat: Add exploded view feature
    This commit introduces an exploded view feature to the model.
    - Added `exploded_view` and `explosion_factor` parameters.
    - Implemented an `explode` module to translate components away from the center.
    - Updated the main assembly to use the `explode` module when `exploded_view` is enabled.
    - Refactored the `explode` module to use a single vector argument for the component center.
    - Updated documentation to reflect the new feature.
    [model.scad]
2025-08-15 feat: Add pedestal
    - A 30mm high pedestal has been added to the bottom of the corpus, raising it from the floor.
    In addition to these new features, the project documentation has been updated to reflect the changes.
    [model.scad]
2025-08-15 feat: Add cut list generation feature
    This commit introduces a new feature to automatically generate a CSV cut list for all the panels required to build the furniture.
    - A new module, `generate_cut_list()`, has been added to the `model.scad` file. This module, controlled by the `generate_cut_list_csv` flag, prints the cut list data to the OpenSCAD console.
    - A PowerShell script, `generate-csv.ps1`, has been created to automate the process of generating the cut list. It runs OpenSCAD, captures the output, and saves the cleaned CSV data to `artifacts/cut_list.csv`.
    - The previous batch script (`generate-csv.bat`) has been replaced by the more robust PowerShell script.
    - The project documentat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
    [cut_list.csv, model.scad, temp_cut_list.csv]
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2025-08-17 feat: Add CNC export workflow
    This commit introduces a new workflow for exporting the 2D panel drawings in DXF format, suitable for CNC cutting services.
    - A PowerShell script, `export-panels.ps1`, has been added to automate the export of all panels from the `model.scad` file.
    - A Python script, `split_layers.py`, has been added to post-process the exported DXF files and separate the geometry into `CUT` and `DRILL` layers.
    - The `model.scad` file has been updated to support the new export workflow.
    - The project documentation (`README.md`, `GEMINI.md`, and `prompt/model-v2.md`) has been updated to reflect the new CNC export workflow.
    [CorpusMiddle.dxf, CorpusMiddle.stl, CorpusSideLeft.dxf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]
2025-08-17 feat: Differentiate drawer sides and fix SVG export
    This commit introduces several improvements to the design and export process.
    The drawer side panels are now differentiated into `DrawerSideLeft` and `DrawerSideRight` to account for the asymmetrical placement of slide mounting holes. The cut list and export logic have been updated to reflect this change.
    The `export-panels.ps1` script has been parameterized to accept the `export_type` as a command-line argument, allowing for more flexible export options. A new script, `export-all.ps1`, has been added to automate the export of all panels in all supported formats (STL, DXF, and SVG).
    The SVG export process has been fixed to ensure that al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
    [CorpusMiddle.dxf, CorpusMiddle.stl, CorpusSideLeft.dxf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]
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2025-08-21 feat: Make hole annotation offset a vector parameter
    Make the `annotation_text_offset` a vector parameter in the `hole_annotation` module. This allows for different offsets for each annotation, which is necessary to keep the annotations within the panel boundaries.
    - The `annotation_text_offset` is now a vector parameter in the `hole_annotation` module.
    - All calls to `hole_annotation` have been updated to use the new `text_offset` parameter.
    - The rotation and position of annotations in several modules have been corrected.
    - A bug where some annotations were placed outside the panel has been fixed.
    [model-with-text-annotations.scad]
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2025-08-22 feat: Refactor hole metadata and DXF export workflow
    Refactored the OpenSCAD model to simplify hole metadata generation and improve the DXF export process.
    - Updated `*_metadata()` functions in `model.scad` to dynamically use `export_panel_name`, enhancing code reusability.
    - Removed all in-model `*_annotations()` modules and related code from `model.scad`, as annotations are now handled externally by `split_layers.py`, improving OpenSCAD export performance.
    - Addressed several issues in `split_layers.py`, including:
    - Corrected entity counting logic during DXF layering.
    - Resolved `AttributeError` related to `get_extents` by using `ezdxf.bbox.extents`.
    - Fixed `UnicodeEncodeErr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
    [#DrawerSideLeft.dxf, CorpusMiddle.csv, CorpusMiddle.dxf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]
2025-08-23 feat: Improve CNC export and hole metadata
    This commit introduces several improvements to the CNC export workflow and the hole metadata generation.
    - **Corrected Hole Coordinates:** The 2D hole coordinate calculation for DXF export has been fixed to resolve issues with reflected coordinates across different panels.
    - **Panel Projections at Origin:** All exported 2D panels are now translated to start at the (0,0) origin and extend into the positive quadrant. This ensures consistency and predictability in the exported DXF files.
    - **Hole Table in DXF:** The `split_layers.py` script now adds a detailed "Hole Schedule" table to the `ANNOTATION` layer of the DXF files. This table includes the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
    [#DrawerSideLeft.dxf, CorpusMiddle.csv, CorpusMiddle.dxf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]
2025-08-23 feat(dxf): Add dimension layer and optimize layout
    This commit introduces a new `DIMENSION` layer to the DXF export, providing detailed dimensions for panels and holes.
    The dimensioning logic in `split_layers.py` has been significantly improved to enhance clarity and readability:
    - Dimensions are now grouped and placed on the closest side of the panel to avoid crossing lines.
    - The script automatically uses unique coordinates to prevent duplicate dimensions.
    - Overall panel dimensions are drawn last to avoid interference with hole dimensions.
    - Dimension text is now placed above the dimension line with a background fill, ensuring it is not crossed by the line.
    The project documentation (`R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
    [CorpusMiddle.dxf, CorpusSideLeft.dxf, CorpusSideRight.dxf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]
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2025-08-28 feat(workflow): add DXF to PDF conversion script
    Introduces a new PowerShell script `convert-dxf-to-pdf.ps1` to automate the conversion of DXF panel drawings to PDF format using LibreCAD.
    The script is designed to be robust against the known issue of LibreCAD's `dxf2pdf` tool returning an incorrect exit code (1) even on success. To handle this, the script verifies the successful creation of the output PDF file instead of relying on the exit code.
    This new script is part of the CNC export workflow, providing an easy way to generate PDF documents for manufacturing or review.
    The project documentation (`README.md`, `GEMINI.md`) has been updated to reflect this new workflow.
    [CorpusMiddle.csv, CorpusMiddle.dwg, CorpusMiddle.dxf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]
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2025-09-14 feat: Refactor and enhance CNC export and order generation
    This commit introduces a series of improvements to the CNC export workflow, order generation, and overall model accuracy.
    - **Model Parameterization:** The main melamine thickness (`melanine_thickness_main`) has been adjusted from 19mm to 18mm to reflect the available material.
    - **DXF Export and Annotations:**
    - The 2D projections for the `DrawerSideLeft`, `DrawerSideRight`, and `DrawerBack` panels have been corrected to ensure they are oriented correctly with the longer side horizontal and are placed in the first quadrant of the DXF file.
    - The corresponding hole metadata functions (`get_drawer_side_hole_2d_coords` and `g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
    [CorpusMiddle.csv, CorpusMiddle.dwg, CorpusMiddle.dxf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]
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2025-09-21 feat: Add Sizekupres order support and fix DXF export bug
    This commit introduces several updates to the project.
    - Adds support for the 'Sizekupres' cutting service to the order generation script.
    - Integrates order generation for all supported services into the main `workflow.ps1` script.
    - Fixes a critical bug in `split_layers.py` that prevented correct identification and deletion of `LINE` entities for holes.
    ### create_order.py
    - Added a new `sizekupres` entry to the `MATERIAL` dictionary with material and edge banding codes.
    - Implemented the `process_sizekupres_order` function to handle the specific format of the Sizekupres order template.
    - The main execution logic is now encapsulate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
    [sizekupres_tablica_za_narudzbu.xlsm, sizekupres_tablica_za_narudzbu.xlsx]
2025-10-26 feat: Update model parameters and order generation
    This commit introduces several updates to the model parameters and order generation scripts.
    - **Model Parameterization:**
    - Changed `melanine_thickness_main` from 19 to 18.
    - Changed `melanine_thickness_secondary` from 12 to 10.
    - **Order Generation:**
    - Updated `create_order.py` to correctly handle banding for the 'Sizekupres' service.
    - Updated material codes for the 'Elgrad' service.
    - **Template Panels:**
    - Changed the material for template panels from 12mm to 18mm melanine.
    - **Documentation:**
    - Updated `README.md`, `GEMINI.md`, and `prompt/model-v2.md` to reflect the changes.
    [model.scad, sizekupres_hrast_sanremo_classic.xls]
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2025-11-23 feat: Adjust drawer side hole position
    This commit adjusts the position of the bottom hole on the drawer's side panels that connects to the back panel. The hole has been moved from 50mm to 35mm from the edge to prevent interference with the drawer slide mechanism.
    This change is reflected in the following locations:
    - `drawer_side_hole_metadata`: The Z-coordinate for the bottom back panel hole is now hardcoded to 35.
    - `drawer_side_drill`: The Z-coordinate for the bottom back panel hole is now hardcoded to 35.
    - `drawer_side_template_hole_metadata`: The Z-coordinate for the bottom back panel hole is now hardcoded to 35.
    Additionally, the `drawer_slide_pilot_hole_offsets` has been updated f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
    [model.scad]
2025-11-29 feat(template): Add handle holes to DrawerFrontTemplate
    Adds 4mm handle holes to the `DrawerFrontTemplate` panel. These holes are identical to the ones on the `DrawerFrontStandard` panel.
    - **`model.scad`**:
    - Added handle holes to the `drawer_front_template_hole_metadata` and `drawer_front_template_drill` modules.
    - Reverted an unintended change to `drawer_side_template_hole_metadata` where `confirmat_hole_edge_distance` was replaced with a hardcoded value.
    - **`test/test-drawer-front-template.ps1`**:
    - Added a new test script to verify the export of the `DrawerFrontTemplate` panel.
    - **Documentation**:
    - Updated changelogs in `README.md`, `GEMINI.m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
    [model.scad]
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2025-12-31 feat: Implement drawer front hole offset and update order materials
    This commit introduces a fix for the vertical offset of dowel and handle holes in drawer front panels, ensuring correct alignment with drawer box components. It also updates the material code for HDF panels in the Iverpan order generation. A new PowerShell test script is added to verify these changes.
    - **model.scad**:
    - Refactored `drawer_front_hole_metadata`, `drawer_front_drill`, and `drawer_front` modules to include a `box_bottom_offset` parameter.
    - Updated calls to these modules (`echo_hole_metadata`, `drawer_front_outside_template_drill`, `draw_fronts`, `export_panel`) to correctly pass `box_bottom_offset` ba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
    [model.scad]
2025-12-31 feat(model): Center drawer front dowel holes
    This commit fixes a bug in the model where the dowel holes on the drawer fronts were not correctly aligned with the center of the drawer side panels. They were previously aligned to the inner face of the side panels.
    - In `drawer_front_drill` and `drawer_front_hole_metadata`, the X-coordinate calculation for the side panel dowel holes has been adjusted. It now correctly offsets the holes from the inner face position by half of `melanine_thickness_secondary` to perfectly center them.
    - **`test/test-drawer-front-alignment.ps1`**:
    - A new test script has been added to programmatically verify the X-axis alignm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
    [model.scad]
